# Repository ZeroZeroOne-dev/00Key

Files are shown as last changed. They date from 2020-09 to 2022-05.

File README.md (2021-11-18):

# 001Key

Custom 75% Keyboard.

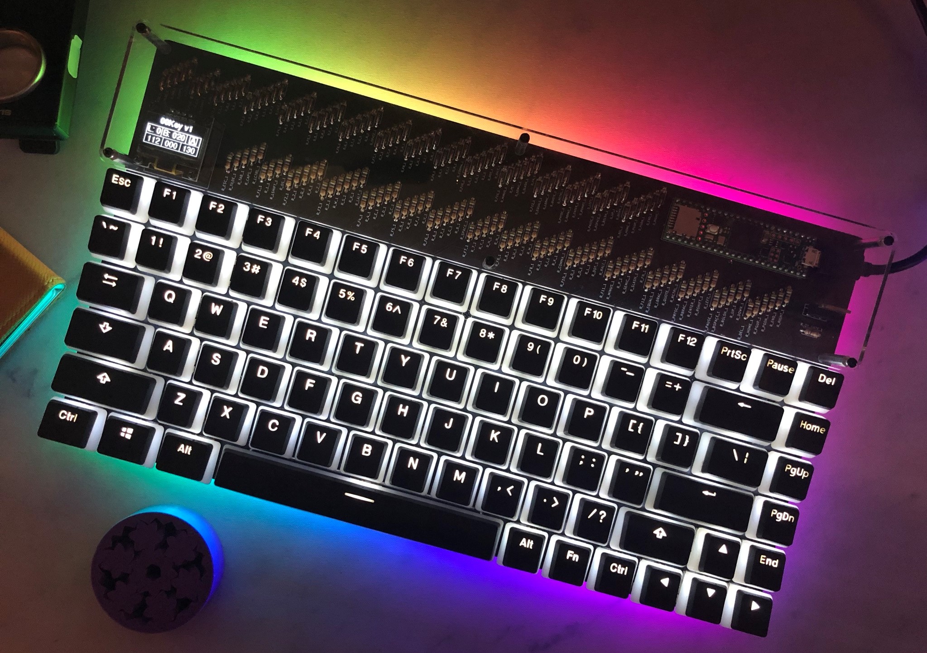
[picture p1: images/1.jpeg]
build


## Hardware

- Teensy 4.1 development board
- SSD1306 0.96 Inch OLED Display
- MX & Alps switch support
- Backlight (single color) support
- RGB Underglow support

## Firmware

Custom firmware, has layer, OLED, Backlight, Underglow support

## OLED display

Displays currently shows

- capslock status
- Selected layer
- backlight intensity 
- Underglow collor selection (RGB Values)

## Underglow

3 Effects
- Solid color
- Rotating rainbow
- Off

## PCB

- Designed in kicad
- Used freerouting for traces

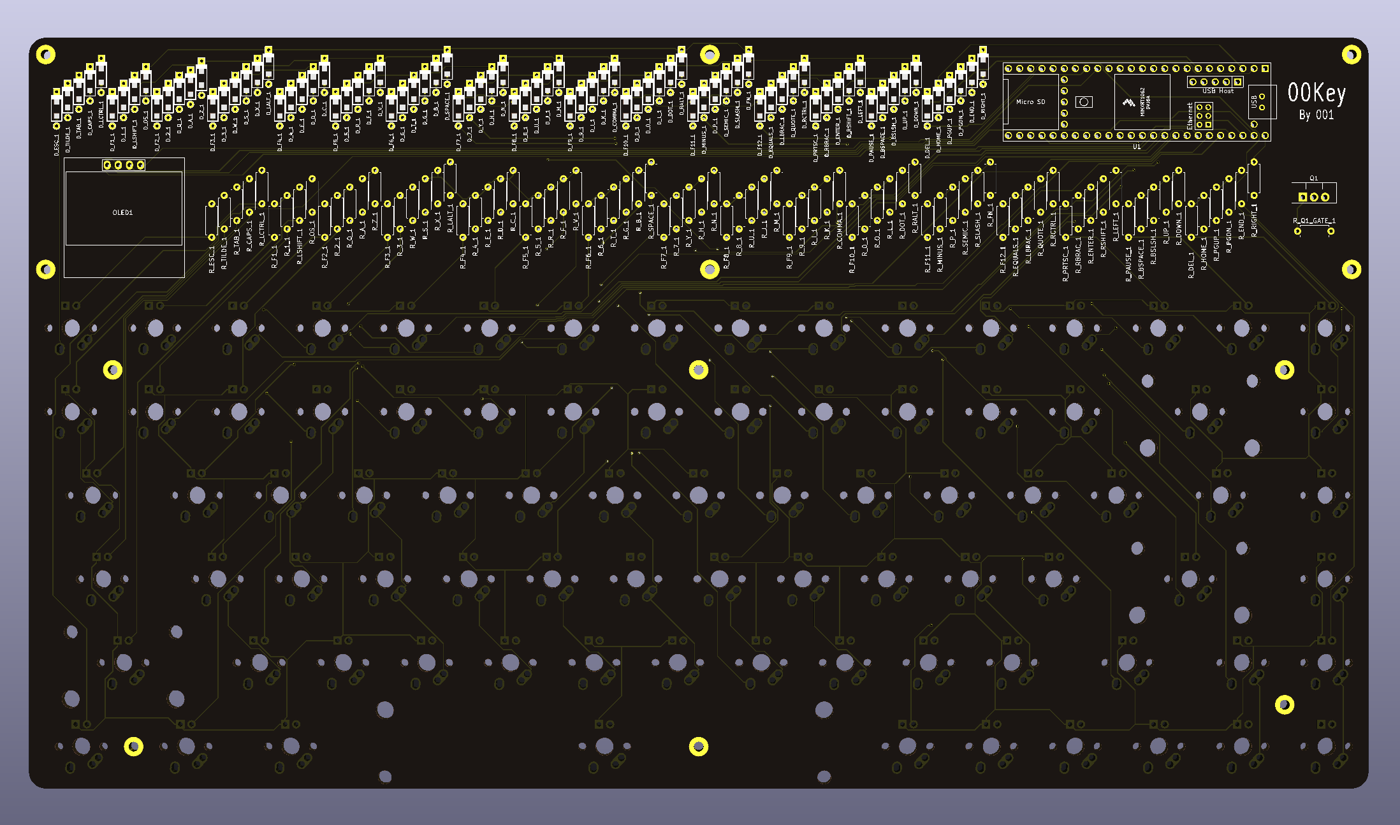
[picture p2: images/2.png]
pcbrender


## Backplate

- Designed in FreeCAD
- Spaced from PCB with (10mm) standoffs
- STL files included for 3D printing in 2 parts

## Case

Stacked acrylic case

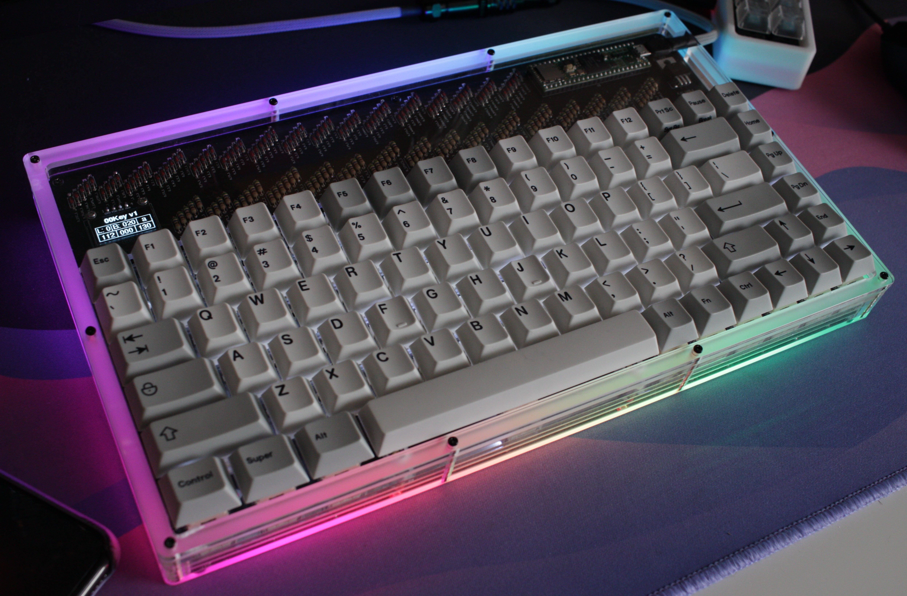
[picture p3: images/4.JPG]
case


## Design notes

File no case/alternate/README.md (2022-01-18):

# Overview

Another bottom to place the PCB on with a 7% slope. This one is almost certinaly only useful if it 
is printed out of clear PETG. Otherwise the light from the RGB LEDs can't be seen.

# OpenSCAD

This is designed with OpenSCAD which can be downloaded at https://www.openscad.org. If you want
to make changes the source files can be edited directly or use the customizer built into OpenSCAD, 
Window --> Customizer.

## Files

| Filename | Note |
| --- | ---- |
| 00keyBottom.scad | The main source file of the design, all the available variables are commented <br/>at the top of the file if you want to change something |
| spacer.scad | The source file for the spacers used to put between the PCB and case |
| cylinders.scad | A library used by spacers.scad, only the `hollowCylinder` module is used | 
| cubes.scad | A library used by 00keyBottom.scad, only the `roundedCube` module is used |

# Assembly
     
The 2 LED strips should be fastened to the bottom of the PCB using Kapton tape or your favorite 
adhesive. They should be positioned so they line up with the slots on the bottom of the case.

The default design intends that the PCB is connected to the case using M2x4x3.5 heat set inserts with
a 2.5 mm spacer in between case and PCB. The size of the hole for the heatset inserts can be
changed in `00keyBottom.scad` if a different size is wanted. The spacers can be made thicker in
`spacer.scad` if thicker spacers are wanted/needed.

The spacers can be held in place with a dab of super glue during assembly so they stay in place as 
the PCB is screwed down.

*NOTE:* I snipped the legs of the controller pins so they didn't stick so far down. If you 
don't do this you will probably need thicker spacers.
          
# Side View
     
Side View
             
# Bottom View

Note that this picture differs slightly from the final design. There is now an anti-flex support running down the middle
of the bottom of the case length-wise.

RGB LED

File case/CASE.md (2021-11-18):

## Acrylic case

The acrylic case can be assembled using M2 standoffs (thin,non-hex), use both male-to-female and female-to-female combined to get the correct lengths.

[amazon link](https://www.amazon.com/dp/B07768Q7YS/ref=cm_sw_em_r_mt_dp_5ADDDQNWRCW3QHP3A56S)

The svg file names should be pretty self-explanatory but here is another summary:

|File|Material|Thickness|Amount|
|---|---|---|---|
|1-foot_4mm_acrylic_x2.svg|Acrylic|4mm|0 - 2|
|2-bottom_5mm_acrylic_x1.svg|Acrylic|5mm|1|
|3-closed_4mm_acrylic_x3.svg|Acrylic|4mm|3|
|4-spacer_2mm_acrylic_x1.svg|Acrylic|2mm|1|
|5-plate_1.5mm_pom_x1.svg|POM|1.5mm|1|
|6-top_usb_3mm_acrylic_x2.svg|Acrylic|3mm|2|
|7-top_2mm_acrylic_x1.svg|Acrylic|2mm|1|

## Manufacturer

You might need to change the coloring and layers of the svg files to the specification of your manufacturer. 
You do have many color choices when using acrylic so let your imagination go wild!

If you're in europe I can recommend [snijlab.nl](https://snijlab.nl) and [laserbeest.nl](https://www.laserbeest.nl/).

For international I heard good things about [ponoko.com](https://www.ponoko.com/).

## Notes

You will have to bend your mosfet into an S-shape so it lays flat on the board.

## Anti-Flex

This part can be 3d printed and screwed to bottom of the top 6 holes of the pcb to provide some stability and to prevent the plate and pcb from flexing too much.

Depending on the calibration of your pinter you might need to tweak the length of the model (you can insert a pause at heigh and stop the print if its too long).

You can experiment yourself if you place them in all 6 holes or any other number of holes.

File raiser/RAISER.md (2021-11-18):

# OLED

The OLED used is a 128*64 SD1306; [aliexpress link](https://www.aliexpress.com/item/32638662748.html?spm=a2g0s.9042311.0.0.5d4e4c4d1zyBQ7)

(GND, VDD, SCK, SDA order)

## OLED Raiser

The oled raiser can be printed to give the lcd a bit of height and stability on the pcb.

Your oled screen might not be the same as the ones i used to its possible that you'll need to tweak the dimensions a bit.

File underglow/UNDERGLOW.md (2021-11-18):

## underglow

A 16 (2x8) led ws2812b rgb strip can be attached to the bottom of the pcb to provide underglow.

Should be soldered to the teensy underside like this: 

black = ground
red = 5v
green = data

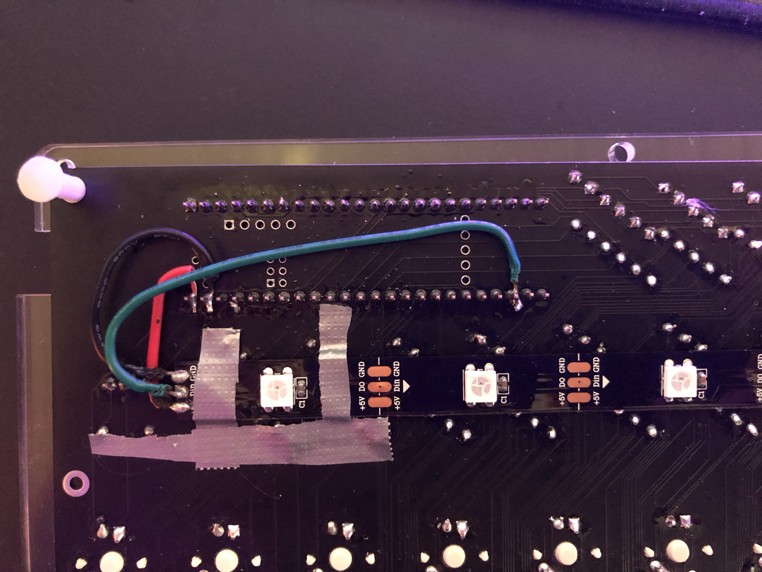
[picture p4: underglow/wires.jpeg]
wiring


In the default keymap the underglow effect can be toggled between static, rainbow, and off with Fn+U

The static effect can be changed using the Fn key in combination with the keys left (value down) and right (value up) of the R, G, and B keys. For example pressing Fn+E will make the Red value go down while pressing Fn+T will make the Red value go up.

## underglow spacer

This can be 3d printed to put over the standoffs between the pcb and the bottom plate 
(not when using the acrylic case).

Provides a convenient place to stick the rgb strips.

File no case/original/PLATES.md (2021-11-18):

## Plates

The top and bottom plate can be attached to the pcb using M2 standoffs (hex) both male-to-female and female-to-female. 

For the bottom you can choose yourself how long the standoffs you want to use are.
(Take into account if you want to put rgb strips in and if you do if you want to use the 3d-printable bracket, you can always switch them around later)

For the top you have to take into account the chosen height for the oled screen and in what position you put your mosfet (S-bended or upright).

[amazon link](https://www.amazon.com/dp/B071KDS14D/ref=cm_sw_em_r_mt_dp_7T1A5SNCJ3JM8QCT1W00)

The bottom plate can either be cut in 5mm acrylic (3mm might also work but i like the extra weight) or 3d printed.

The top plate should be cut in acrylic (2mm minimum for strength).

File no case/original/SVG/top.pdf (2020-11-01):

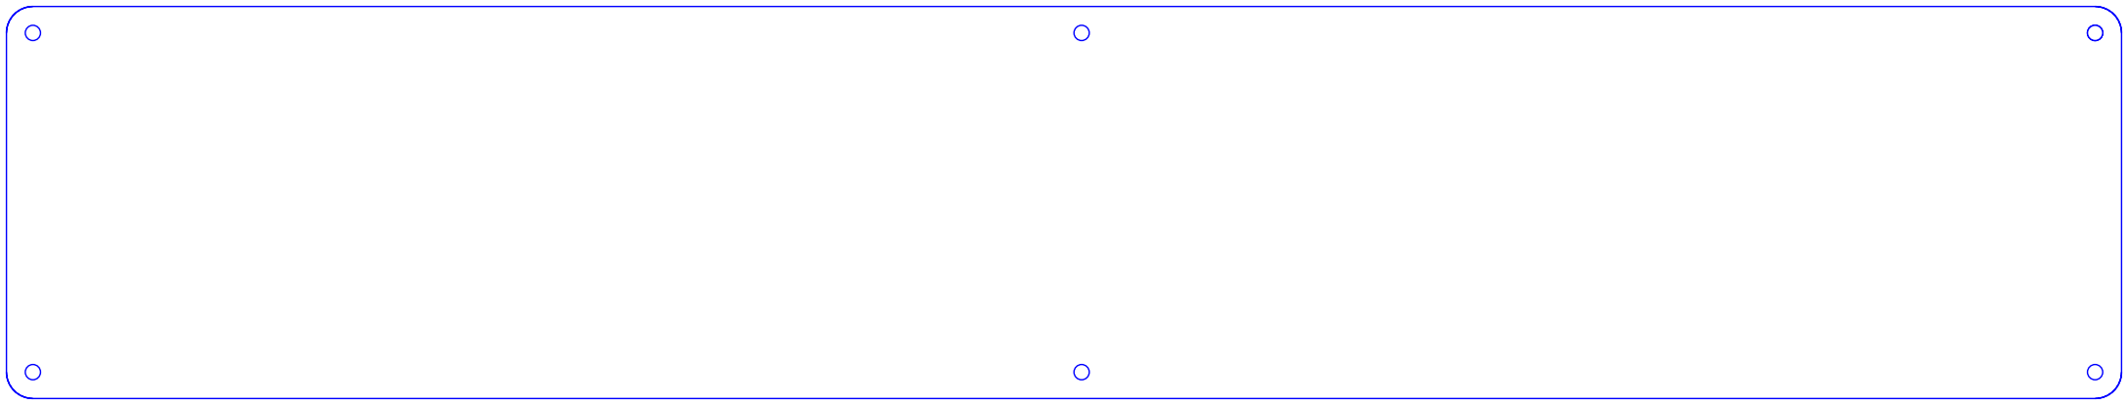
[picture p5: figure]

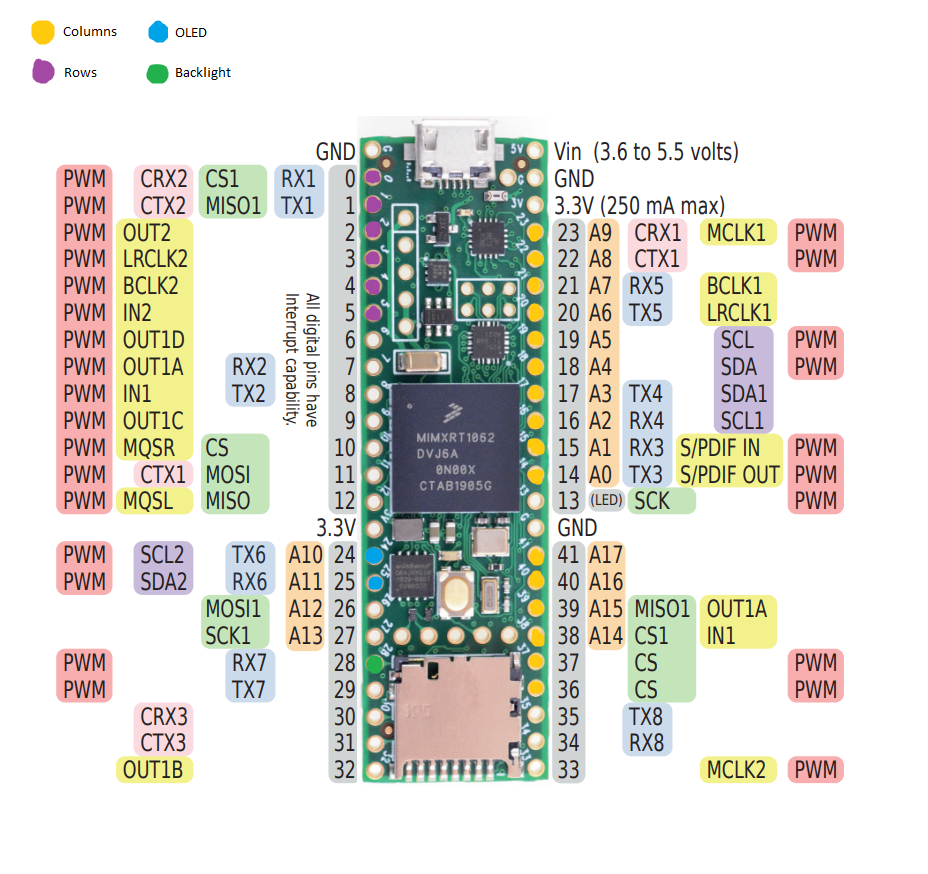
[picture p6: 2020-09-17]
reference/pins.png

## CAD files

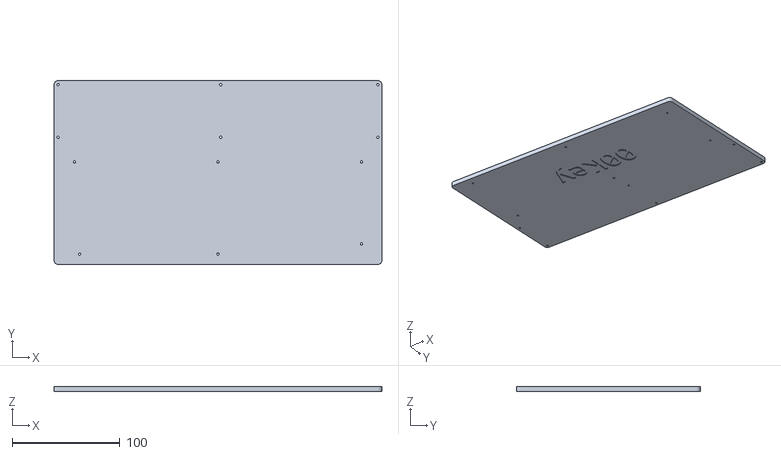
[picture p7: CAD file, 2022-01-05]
no case/original/STL/full.stl
304.8 x 170.8 x 5.00

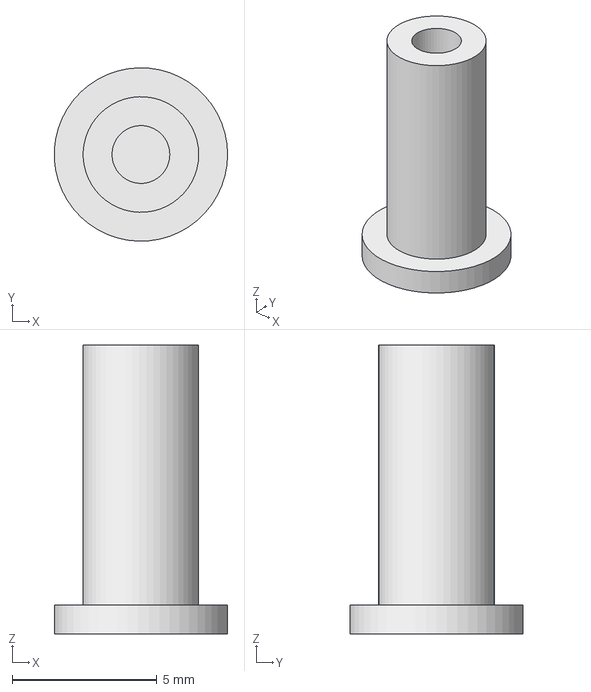
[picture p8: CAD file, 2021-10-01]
case/CAD/anti-flex.FCStd
5.99 x 6.00 x 10.0 mm

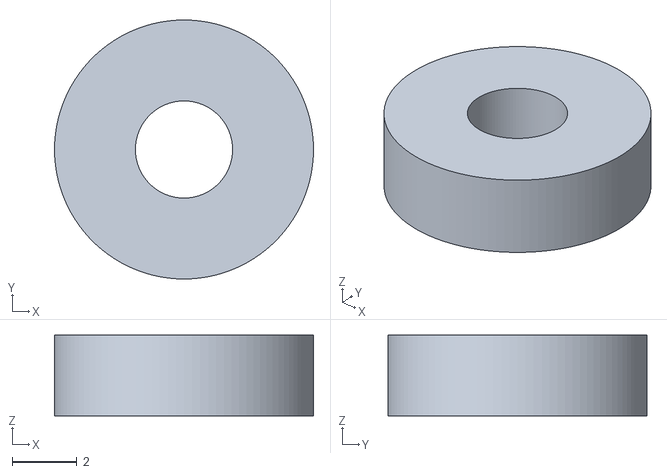
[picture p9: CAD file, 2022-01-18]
no case/alternate/STL/spacer.stl
8.00 x 8.00 x 2.50

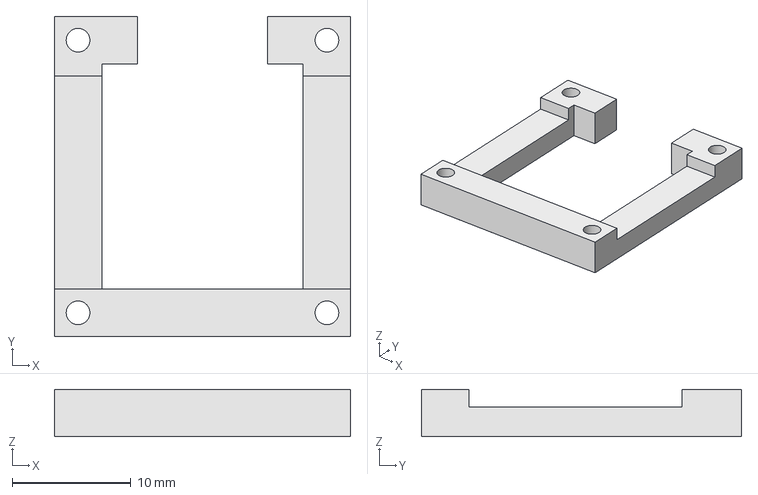
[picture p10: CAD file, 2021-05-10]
raiser/CAD/raiser.FCStd
25.0 x 27.0 x 4.00 mm

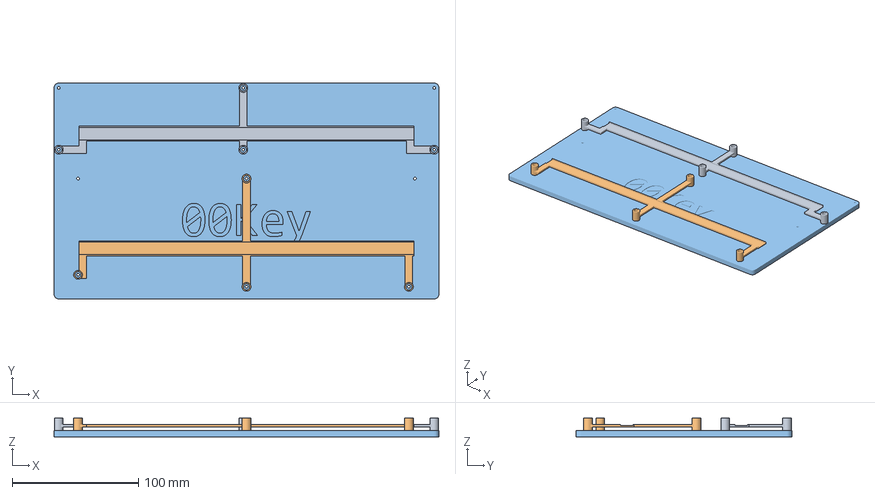
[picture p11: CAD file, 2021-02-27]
underglow/CAD/underglow spacer.FCStd
304.8 x 170.8 x 15.0 mm
top_all
bottom_all
plate

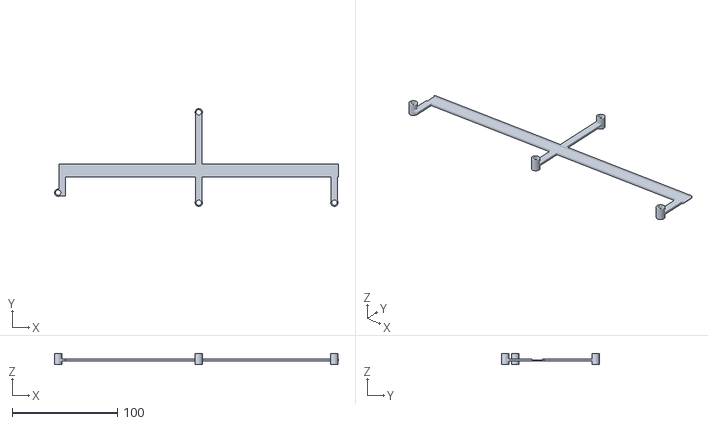
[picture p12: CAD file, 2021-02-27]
underglow/STL/underglow_spacer_bottom.stl
269.3 x 92.7 x 10.0

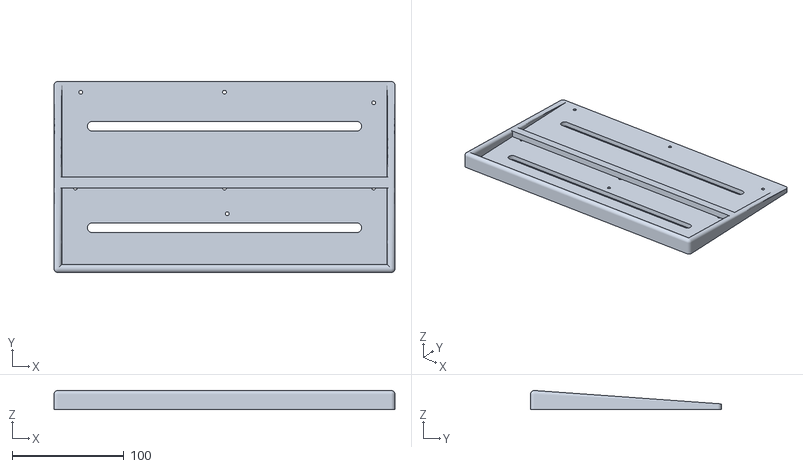
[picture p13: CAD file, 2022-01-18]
no case/alternate/STL/00keyBottom.stl
304.8 x 170.7 x 17.0

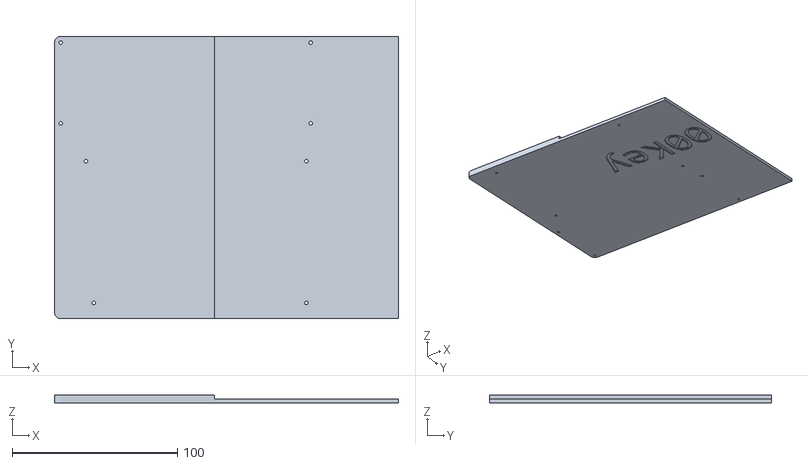
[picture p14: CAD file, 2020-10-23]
no case/original/STL/right.stl
208.1 x 170.8 x 5.00

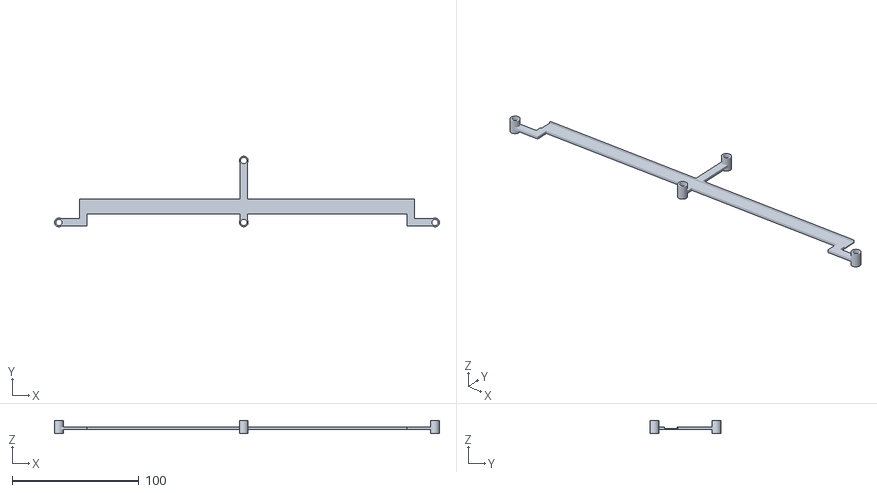
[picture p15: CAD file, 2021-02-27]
underglow/STL/underglow_spacer_top.stl
304.2 x 55.8 x 10.0

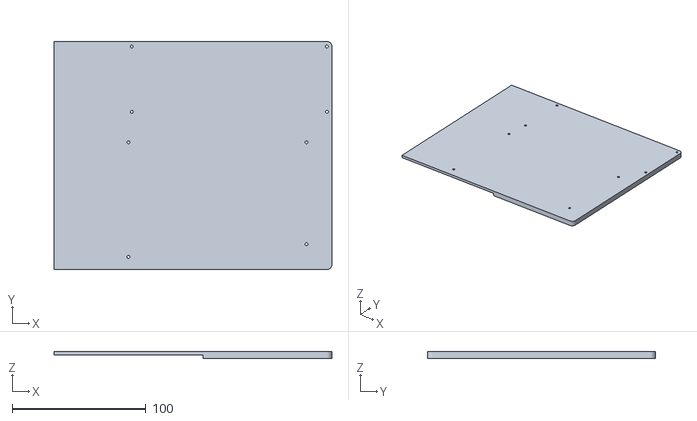
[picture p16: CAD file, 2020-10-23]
no case/original/STL/left.stl
208.1 x 170.8 x 5.00

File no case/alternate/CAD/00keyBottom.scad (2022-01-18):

use <cubes.scad>
 
$fn = 100;

//Length is x-axis and width is y-axis prior to to any rotation
length = 304.8;
width = 170.69;
height = 5;

//My radius gauge put the radius of the PCB corners somwhere betwen 3 and 4, went with 3.5 
//and it seems to match up pretty good
cornerRadius = 3.5;

//The outside diamter of the heatset insert you are using. I find it easier to insert these if the hole
//is tapered. So this value will be the diameter of the bottom of the hole. The diameter of the 
//top of the hole will be (heatsertOutsideDiameter + topHoleDelta). If you just want a non-tapered hole
//of a certain size just set the diameter appropriately and set topHoleDelta to 0
heatsertOutsideDiameter = 3.4;
topHoleDelta = 0.4;

//The height of the rear of the case, percent slope is (rearHeight / width * 100). 6-8% slope is common for keyboards. 
//10.5 gives ~6%, 
//12 gives ~7% slope.
//13.7 gives ~8%
//The calculated slope is printed in the console for convenience
rearHeight = 12;

//If you want to include the slots for the RGB lights this should be true, false otherwise
includeRgbLightHoles = true;

//The length (x-axis) of the RGB slot, make it long enough so all the LEDs are visible. The default 
//value should be good for 30 LED/meter strips. 
lightHoleLength = 245;

//The width (y-axis) of the RGB slot. This value is probably good to leave alone but you can adjust if you want
lightHoleWidth = 8.5;

//The y-axis position of the 1st RGB slot
lightHoleY1 = 40;

//The y-axis position of the 2nd RGB slot. Its default value will keep it equidistant from the edge as the 
//position of the 1st RGB slot
lightHoleY2 = width - lightHoleY1;

//How wide to make the anti-flex support. 
antiFlexWidth = 10;

//The position of the anti-flex support. The default value covers the holes a bit but the heatset inserts 
//don't come out the bottom so it doesn't matter. Can subtract antiFlexWidth from this if that bothers you 
antiFlexPosition = width / 2;

//Measured the hole distances on the PCB in KiCad with the measure tool. 
holeEdgeDistance = 3.81;
y1 = width - holeEdgeDistance;
y2 = 118.2;
y3 = 95.25;
y4 = 9.53;
holePositions = [
    //Row 1 (from top)
    [holeEdgeDistance, y1],
    [154.94, y1],
    [length - holeEdgeDistance, y1],
    //Row 2 (from top)
    [holeEdgeDistance, y2],
    [154.94, y2],
    [length - holeEdgeDistance, y2],
    //Row 3 (from top)
    [19.05, y3],
    [152.4, y3],
    [length - 19.05, y3],
    //Row 4 (from top)
    [23.88, y4],
    [152.4, y4],
    //The one-off hole in bottom right
    [length - 19.05, 19.05]
];

heatsertHoleTopDiameter = heatsertOutsideDiameter + topHoleDelta;

echo("Percent Slope: ", rearHeight / width * 100);
echo("LightHoleY1: ", lightHoleY1);
echo("LightHoleY2: ", lightHoleY2);

//Translating and rotating to get it in print orientation at the origin
//If you make changes comment out the translate/rotate line until you are ready to render/export
//as it gets confusing if you don't
translate([0, width, 0])  rotate([180, 0, 0]) 
main();

module main() {
    difference() {
        roundedCube(length = length, width = width, height = height, radius = cornerRadius, center = false, roundingShape = "circle", topRoundingShape = undef);
        screwHoles();
        if (includeRgbLightHoles) {
            rgbLightHoles();
        }
    }

    slant();
    //This will give additional support in the middle of the case, especially if RGB holes are included. If no RGB holes are included
    //you might be able to get away with not having this if you want.
    antiFlex();
}

module screwHoles() {
    for (pos = holePositions) {
       translate(concat(pos, -0.01)) cylinder(d1 = heatsertOutsideDiameter, d2 = heatsertHoleTopDiameter, h = height + 0.02, center = false);
    }
}

module slant() {
    slantPoints = [
        [cornerRadius, cornerRadius], //bottom left
        [cornerRadius, width - cornerRadius], //top left
        [length - cornerRadius, width - cornerRadius], //top right
        [length - cornerRadius, cornerRadius] //bottom right
    ];

    //Basically drawing a polyline with the rear/front objects hulled together
    hull() {
        translate(slantPoints[0]) frontObject();
        translate(slantPoints[1]) rearObject();
    }

    hull() {
        translate(slantPoints[1]) rearObject();
        translate(slantPoints[2]) rearObject();
    }

    hull() {
        translate(slantPoints[2]) rearObject();
        translate(slantPoints[3]) frontObject();
    }

    module rearObject() {
        //The radius of the sphere is effectively added to the height of the cylinder so to make the rear be the height we 
        //actually want need to subtract the radius
        cylinderHeight = rearHeight - cornerRadius;

        translate([0, 0, -cylinderHeight]) {
            cylinder(r = cornerRadius, h = cylinderHeight);
            sphere(r = cornerRadius);
        }
    }

    module frontObject() {
        //Don't want to add any meaningful dimension to the front of the case so make this
        //super thin just so we have something to hull with
        bottomHeight = 0.01;
        translate([0, 0, -bottomHeight]) cylinder(r = cornerRadius, h = bottomHeight);
    }
}

module rgbLightHoles() {
    x = length / 2 - lightHoleLength / 2;
    translate([x, lightHoleY1, -0.5]) rgbLightHole();
    translate([x, lightHoleY2, -0.5]) rgbLightHole();

    module rgbLightHole() {
        adjustedLength = lightHoleLength - lightHoleWidth;
        
        //Translate the radius of the hole so it is at the origin
        translate([lightHoleWidth / 2, 0, 0]) hull() {
            cylinder(d = lightHoleWidth, h = height + 1);
            translate([adjustedLength, 0, 0]) cylinder(d = lightHoleWidth, h = height + 1);
        }
    }
}

module antiFlex() {
    //We want the antiflex support to be the same height as the slanted walls at its position. So 
    //we will draw the slant again and intersect a cube with it, then hull the result of the intersection.
    //I normally like drawing my objects at the origin in modules and them moving them into position where they 
    //are used; however, in this case the height of the antiFlex object depends on where it is positioned on the y-axis 
    //so have to move it into position here as well
    height = rearHeight + 10;
    hull() {
        intersection() {
            slant();
            translate([0, antiFlexPosition, -height]) cube([length, antiFlexWidth, height]);
        }
    }
}

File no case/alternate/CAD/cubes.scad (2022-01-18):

//dimensionType -- "inner" if the passed in dimensions are for the inside of the box i.e. the hollow parts (default), 
//  "outer" if the passed in dimensions are for the outside of the box. In this case the dimensions of the hollow part
//  will be calculated taking into account the passed in wallThickness
//hasFloor = true to make it a box with a floor, false to make the hole all the way through
module hollowCube(length = 10, width = 10, height = 10, wallThickness = 3, hasFloor = true, dimensionType = "inner", center = false, debug = false) {
    doubleWallThickness = wallThickness * 2;

    if (dimensionType == "inner") {
        echo("InnerDimensioned Hollow Cube");
        innerDimensioned();
    } else {
        echo("OuterDimensioned Hollow Cube");
        outerDimensioned();
    }

    module innerDimensioned() {
        difference() {
            //Exterior
            exteriorLength = length + doubleWallThickness;
            exteriorWidth = width + doubleWallThickness;
            if (debug) {
                echo("Wall Thickess: ", wallThickness);
                echo("Double Wall Thickess: ", doubleWallThickness);
                echo("Inner Length: ", length);
                echo("Inner Width: ", width);
                echo("Exterior Length: ", exteriorLength);
                echo("Exterior Width: ", exteriorWidth);
            }

            cube([exteriorLength, exteriorWidth, height], center = center);

            //Hollow interior
            x = center == true ? 0 : wallThickness;
            y = center == true ? 0 : wallThickness;
            if (hasFloor == true) {
                translate([x, y, wallThickness]) cube([length, width, height], center = center);
            } else {
                translate([x, y, -1]) cube([length, width, height + 10], center = center);
            }
        }
    }

    module outerDimensioned() {
        difference() {
            //Exterior
            innerLength = length - doubleWallThickness;
            innerWidth = width - doubleWallThickness;
            echo("Wall Thickess: ", wallThickness);
            echo("Double Wall Thickess: ", doubleWallThickness);
            echo("Exterior Length: ", length);
            echo("Exterior Width: ", width);
            echo("Inner Length: ", innerLength);
            echo("Inner Width: ", innerWidth);

            cube([length, width, height], center = center);

            //Hollow interior
            x = center ? 0 : wallThickness;
            y = center ? 0 : wallThickness;
            if (hasFloor) {
                translate([x, y, wallThickness]) cube([innerLength, innerWidth, height], center = center);
            } else {
                translate([x, y, -1]) cube([innerLength, innerWidth, height + 10], center = center);
            }
        }
    }
}

//dimensionType -- "inner" if the passed in dimensions are for the inside of the box i.e. the hollow parts (default), 
//  "outer" if the passed in dimensions are for the outside of the box. In this case the dimensions of the hollow part
//  will be calculated taking into account the passed in wallThickness
//hasFloor = true to make it a box with a floor, false to make the hole all the way through
//roundingShape = one of "sphere" or "circle", a sphere rounds the object along all edges, circle rounds just the corners
//  if topRoundingShape is undef this applies to all edges
//topRoundingShape = one of "sphere" or "circle", a sphere rounds the object along all edges, circle rounds just the corners
//  if defined is the rounding shape of the top edges in case you want top edges rounded differently (can be handy for lids)
module hollowRoundedCube(length = 10, width = 10, height = 10, radius = 1, wallThickness = 3, floorThickness = 3, hasFloor = true, 
    roundingShape = "sphere", topRoundingShape = undef, dimensionType = "inner", roundedInterior = false, center = false) {

    topRoundingShape = topRoundingShape == undef ? roundingShape : topRoundingShape;
    echo("TopRoundingShape: ", topRoundingShape);

    doubleWallThickness = wallThickness * 2;
    if (dimensionType == "inner") {
        innerDimensioned();
    } else {
        outerDimensioned();
    }

    module innerDimensioned() {
        difference() {
            //Exterior
            roundedCube(length + doubleWallThickness, width + doubleWallThickness, height, radius, roundingShape = roundingShape, 
                topRoundingShape = topRoundingShape, center = center);

            //Hollow interior
            x = center ? 0 : wallThickness;
            y = center ? 0 : wallThickness;
            if (hasFloor) {
                translate([x, y, floorThickness]) hollowInterior(length, width, height, center = center);
            } else {
                translate([x, y, -1]) hollowInterior(length, width, height + 10, center = center);
            }
        }
    }

    module outerDimensioned() {
        innerLength = length - doubleWallThickness;
        innerWidth = width - doubleWallThickness;
        difference() {
            //Exterior
            roundedCube(length, width, height, radius, roundingShape = roundingShape, topRoundingShape = topRoundingShape, center = center);

            //Hollow interior
            x = center ? 0 : wallThickness;
            y = center ? 0 : wallThickness;
            if (hasFloor) {
                translate([x, y, floorThickness]) hollowInterior(innerLength, innerWidth, height, center = center);
            } else {
                translate([x, y, -1]) hollowInterior(innerLength, innerWidth, height + 10, center = center);
            }
        }
    }

    module hollowInterior(length, width, height, center = center) {
        if (roundedInterior) {
            roundedCube(length, width, height, radius, roundingShape = roundingShape, topRoundingShape = topRoundingShape, center = center);
        } else {
            cube([length, width, height], center = center);
        }
    }
}

/*
    Creates rounded cube without minkowsi, this one performs a lot better than minowski cube which may be important 
    in larger designs

    roundingSphere = one of "sphere" or "circle", a sphere rounds the object along all edges, circle rounds just the corners
*/
module roundedCube(length = 10, width = 10, height = 10, radius = 1, center = false, roundingShape = "sphere", topRoundingShape = undef) {
    topRoundingShape = topRoundingShape == undef ? roundingShape : topRoundingShape;
    echo("roundedCube(), TopRoundingShape: ", topRoundingShape);
    if (center) {
        centeredRoundedCube();
    } else {
        nonCenteredRoundedCube();
    }

    module centeredRoundedCube() {
        bottomZ = roundingShape == "sphere" ? -(height - (radius * 2)) / 2 : -height / 2;
        topZ = topRoundingShape == "sphere" ? (height - (radius * 2)) / 2 : height / 2;

        echo("Centered Rounded Cube");
        echo("height: ", height);
        echo("BottomZ: ", bottomZ);
        echo("TopZ: ", topZ);

        hull() {
            translate([0, 0, bottomZ]) rectangle(length, width, radius, roundingShape);
            translate([0,0, topZ]) rectangle(length, width, radius, topRoundingShape);
        }
    }

    module nonCenteredRoundedCube() {
        z1 = topRoundingShape == "sphere" ? height - radius : height ;
        z2 = roundingShape == "sphere" ? radius : 0;
        x = length / 2;
        y = width / 2;
        echo("Non-Centered Rounded Cube");
        echo("length: ", length);
        echo("width: ", width);
        echo("height: ", height);
        echo("radius: ", radius);
        echo("x: ", x);
        echo("y: ", y);
        echo("Z1: ", z1);
        echo("Z2: ", z2);

        hull() {
            //Top
            translate([x, y, z1]) rectangle(length, width, radius, topRoundingShape);
            //Bottom
            translate([x, y, z2]) rectangle(length, width, radius, roundingShape);
        }
    }

    module rectangle(length, width, radius, roundingShape) {
        x = length - radius;
        y = width - radius;
        hull() {
            translate([(-x/2)+(radius/2), (-y/2)+(radius/2), 0]) roundingShape(radius, roundingShape);
            translate([(x/2)-(radius/2), (-y/2)+(radius/2), 0]) roundingShape(radius, roundingShape);
            translate([(-x/2)+(radius/2), (y/2)-(radius/2), 0]) roundingShape(radius, roundingShape);
            translate([(x/2)-(radius/2), (y/2)-(radius/2), 0]) roundingShape(radius, roundingShape);
        }

        module roundingShape(radius, roundingShape) {
            if (roundingShape == "sphere") {
                sphere(r = radius);
            } else {
                //make the extrusion small to make it a 3d object but don't add any size to the requested dimensions
                linear_extrude(0.000000000001) circle(r = radius);
            }
        }
    }
}

//Produces a 2D rounded square
module roundedSquare(length = 10, width = 10, radius = 1.0) {
    x = length - radius;
    y = width - radius;
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

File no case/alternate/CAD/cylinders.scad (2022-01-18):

use <../bosl/constants.scad>
include <../bosl/threading.scad>
use <shapes.scad>

//Creates a rod with threads on one or both ends. These rods can be threaded into each other
//
// endType -- one of "both", "male", or "female". If "both" the rod with have a female thread on one end and a male thread
//  on the other. If "male" one end with have a male thread and the other end will be flat. If "female" one end will have a 
//  female thread and the other end will be flat.
module rodWithThreads(diameter = 10, height = 100, endType = "both", threadDiameter = undef, threadLength = 5, threadPitch = 1, threadHoleAdjustment = 0.5, $fn = undef) {
    //For female threads difference this out of an object, send in a positive threadHoleAdjustment to make
    //the female hole bigger than the male threads
    threadDiameter = threadDiameter == undef ? diameter / 2 : threadDiameter;
    echo("Thread Diameter: ", threadDiameter);
    $fn = $fn == undef ? diameter * 2 : $fn;
    echo("$fn: ", $fn);
    difference() {

        union() {
            cylinder(d = diameter, h = height, center = false);

            //Create male thread if requested
            if (endType == "both" || endType == "male") {
                echo("****male****");
                translate([0, 0, height - 0.01]) thread(threadDiameter, threadLength, threadPitch);
            } 
        }

        //Create female thread if requested
        if (endType == "both" || endType == "female") {
            echo("****female****");
            translate([0, 0, -1]) thread(threadDiameter, threadLength + 2, threadPitch, threadHoleAdjustment, internal = true);
        }
    }

    module thread(threadDiameter, threadLength, threadPitch,  threadHoleAdjustment = 0, internal = false) {
        echo("ThreadHoleAdjustement: ", threadHoleAdjustment);
        threaded_rod(d = threadDiameter, l = threadLength, pitch = threadPitch, internal = internal, slop = threadHoleAdjustment, orient=ORIENT_Z, align=V_UP);
    }
}

// floorThickness - how thick the floor is if hasFloor is true, if left undefined then floor thickness is (outerDiameter - innerDiamter) / 2
module hollowCylinder(outerDiameter = 5, innerDiameter = 4, topOuterDiameter = undef, topInnerDiameter = undef, height = 10, center = false, hasFloor = false, 
    rounded = undef, floorThickness = undef) {
    topOuterDiameter = topOuterDiameter == undef ? outerDiameter : topOuterDiameter;
    topInnerDiameter = topInnerDiameter == undef ? innerDiameter : topInnerDiameter;
    echo("OuterDiameter: ", outerDiameter);
    echo("TopOuterDiameter: ", topOuterDiameter);
    echo("InnerDiameter: ", innerDiameter);
    echo("TopInnerDiameter: ", topInnerDiameter);
    echo("Rounded: ", rounded);
    echo("HasFloor: ", hasFloor);

    floorThickness = floorThickness == undef ? (outerDiameter - innerDiameter) / 2 : floorThickness;
    echo("FloorThickness (if hasFloor = true): ", floorThickness);


    if (rounded == undef) {
        nonRoundedTop();
    } else if (rounded == "top") {
        roundedTop();
    } else {
        roundedBottom();
    }

    z = hasFloor ? floorThickness : -0.01; 
    echo("Z: ", z);

    module nonRoundedTop() {
        difference() {
            cylinder(d1 = outerDiameter, d2 = topOuterDiameter, height, center = center);
            translate([0, 0, z]) cylinder(d1 = innerDiameter, d2 = topInnerDiameter, height + 1, center = center);
        }
    }

    //Center = true doesn't yet work with rounded cylinders
    module roundedTop() {
        //Wall thickness is the diameter of the circle that makes up the torus, so substract that from the height so we get the right height
        difference() {
            hull() {
                translate([0, 0, height - floorThickness]) torus(radiusOfTorus = topOuterDiameter / 2, diameterOfCircle = floorThickness, dimensionType = "outer", center = center);
                cylinder(d = outerDiameter, h = 1, center = center);
            }

            translate([0, 0, z]) cylinder(d1 = innerDiameter, d2 = topInnerDiameter, h = height + 1, center = center);
        }
    }

    //Center = true doesn't yet work with rounded cylinders
    module roundedBottom() {
        //Wall thickness is the diameter of the circle that makes up the torus, so substract that from the height so we get the right height
        difference() {
            hull() {
                translate([0, 0, height - 1]) cylinder(d1 = outerDiameter, d2 = topOuterDiameter, h = 1, center = center);
                torus(radiusOfTorus = outerDiameter / 2, diameterOfCircle = floorThickness, dimensionType = "outer", center = center);
            }

            translate([0, 0, z]) cylinder(d1 = innerDiameter, d2 = topInnerDiameter, h = height + 1, center = center);
        }
    }
}

//A cylinder with rouned edges on top and bottom
module roundedCylinder(diameter = 10, roundedRadius = 2, height = 20, center = false) {
    radius = diameter / 2;
    hull() {
        torus(radiusOfTorus = radius, diameterOfCircle = roundedRadius, dimensionType = "outer", center = center);
        translate([0, 0, height - roundedRadius]) torus(radiusOfTorus = diameter / 2, diameterOfCircle = roundedRadius, dimensionType = "outer", center = center);
    }
}

//Test
//rodWithThreads(diameter = 23, height = 100, endType = "both", threadLength = 20, threadPitch = 2, threadHoleAdjustment = 0.8);
//roundedCylinder(diameter = 20, roundedRadius = 4, center = false);
$fn = 100;
hollowCylinder(outerDiameter = 84, innerDiameter = 81, topOuterDiameter = 125, topInnerDiameter = 122, height = 113, center = false, hasFloor = true, rounded = "top", floorThickness = 3);

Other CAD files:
no case/alternate/CAD/spacer.scad
case/STL/anti-flex.stl
raiser/STL/raiser.stl

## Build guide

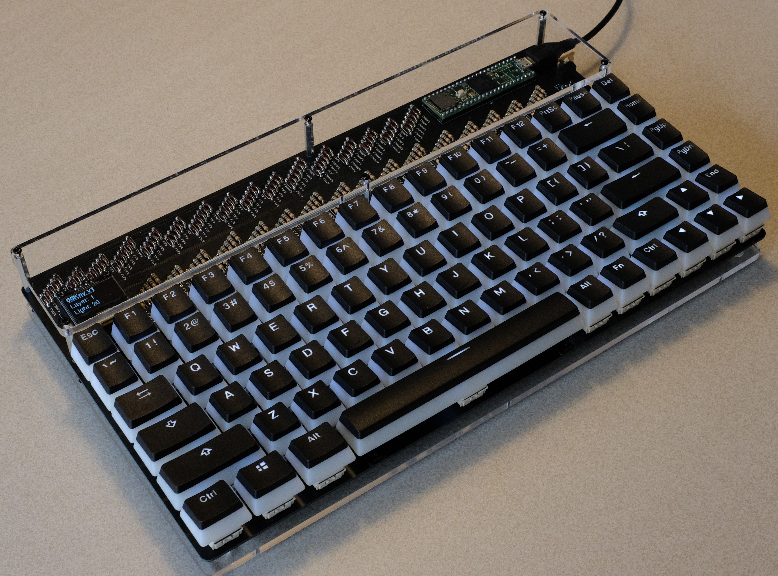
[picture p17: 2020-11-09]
images/build/DSCF2616.JPG

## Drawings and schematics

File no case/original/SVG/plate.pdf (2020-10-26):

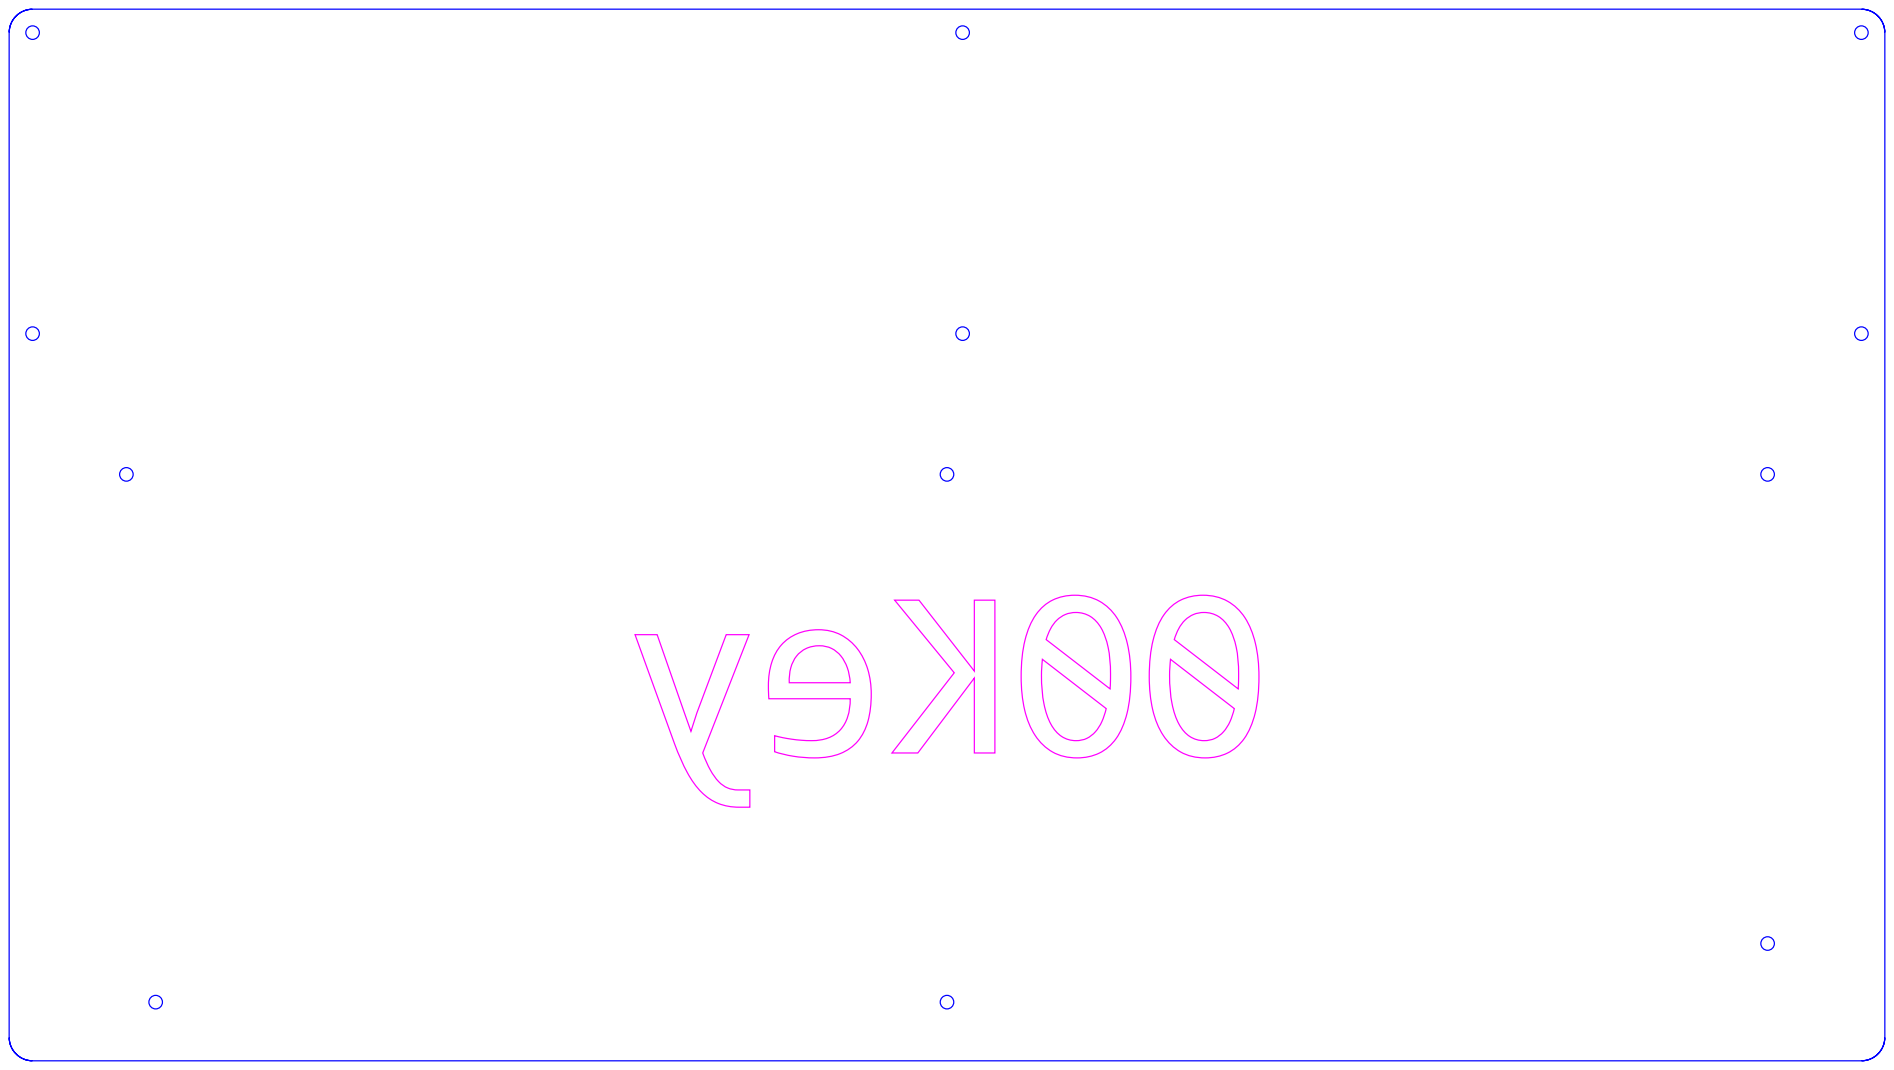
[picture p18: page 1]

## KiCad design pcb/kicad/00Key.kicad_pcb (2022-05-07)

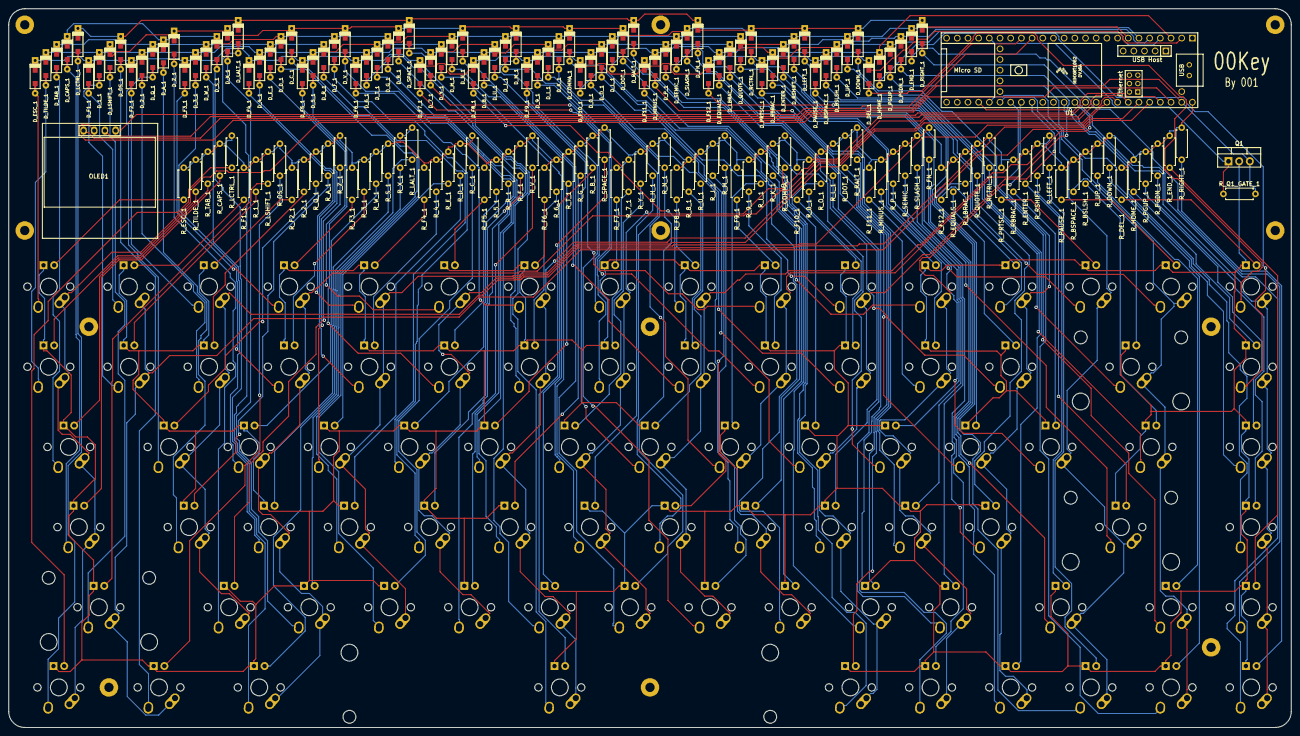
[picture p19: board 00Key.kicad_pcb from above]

Board: 2 copper layers, 304.8 x 170.8 mm, 268 parts (0 on the bottom side), 197 nets.

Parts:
D_0_1, D_1_1, D_2_1, D_3_1, D_4_1, D_5_1, D_6_1, D_7_1, D_8_1, D_9_1: D; D_SOD123_axial
D_A_1: D; D_SOD123_axial
D_BSLSH_1: D; D_SOD123_axial
D_BSPACE_1: D; D_SOD123_axial
D_B_1: D; D_SOD123_axial
D_CAPS_1: D; D_SOD123_axial
D_COMMA_1: D; D_SOD123_axial
D_C_1: D; D_SOD123_axial
D_DEL_1: D; D_SOD123_axial
D_DOT_1: D; D_SOD123_axial
D_DOWN_1: D; D_SOD123_axial
D_D_1: D; D_SOD123_axial
D_END_1: D; D_SOD123_axial
D_ENTER_1: D; D_SOD123_axial
D_EQUALS_1: D; D_SOD123_axial
D_ESC_1: D; D_SOD123_axial
D_E_1: D; D_SOD123_axial
D_F1_1, D_F2_1, D_F3_1, D_F4_1, D_F5_1, D_F6_1, D_F7_1, D_F8_1, D_F9_1, D_F10_1, D_F11_1, D_F12_1: D; D_SOD123_axial
D_FN_1: D; D_SOD123_axial
D_F_1: D; D_SOD123_axial
D_G_1: D; D_SOD123_axial
D_HOME_1: D; D_SOD123_axial
D_H_1: D; D_SOD123_axial
D_I_1: D; D_SOD123_axial
D_J_1: D; D_SOD123_axial
D_K_1: D; D_SOD123_axial
D_LALT_1: D; D_SOD123_axial
D_LBRAC_1: D; D_SOD123_axial
D_LCTRL_1: D; D_SOD123_axial
D_LEFT_1: D; D_SOD123_axial
D_LSHIFT_1: D; D_SOD123_axial
D_L_1: D; D_SOD123_axial
D_MINUS_1: D; D_SOD123_axial
D_M_1: D; D_SOD123_axial
D_N_1: D; D_SOD123_axial
D_OS_1: D; D_SOD123_axial
D_O_1: D; D_SOD123_axial
D_PAUSE_1: D; D_SOD123_axial
D_PGDN_1: D; D_SOD123_axial
D_PGUP_1: D; D_SOD123_axial
D_PRTSC_1: D; D_SOD123_axial
D_P_1: D; D_SOD123_axial
D_QUOTE_1: D; D_SOD123_axial
D_Q_1: D; D_SOD123_axial
D_RALT_1: D; D_SOD123_axial
D_RBRAC_1: D; D_SOD123_axial
D_RCTRL_1: D; D_SOD123_axial
D_RIGHT_1: D; D_SOD123_axial
D_RSHIFT_1: D; D_SOD123_axial
D_R_1: D; D_SOD123_axial
D_SEMIC_1: D; D_SOD123_axial
D_SLASH_1: D; D_SOD123_axial
D_SPACE_1: D; D_SOD123_axial
D_S_1: D; D_SOD123_axial
D_TAB_1: D; D_SOD123_axial
D_TILDE_1: D; D_SOD123_axial
D_T_1: D; D_SOD123_axial
D_UP_1: D; D_SOD123_axial
D_U_1: D; D_SOD123_axial
D_V_1: D; D_SOD123_axial
D_W_1: D; D_SOD123_axial
D_X_1: D; D_SOD123_axial
D_Y_1: D; D_SOD123_axial
D_Z_1: D; D_SOD123_axial
H_KEYS_BL: MountingHole_2.2mm_M2_Pad
H_KEYS_BM: MountingHole_2.2mm_M2_Pad
H_KEYS_BR: MountingHole_2.2mm_M2_Pad
H_KEYS_TL: MountingHole_2.2mm_M2_Pad
H_KEYS_TM: MountingHole_2.2mm_M2_Pad
H_KEYS_TR: MountingHole_2.2mm_M2_Pad
H_PLATE_BL: MountingHole_2.2mm_M2_Pad
H_PLATE_BR: MountingHole_2.2mm_M2_Pad
H_PLATE_MB: MountingHole_2.2mm_M2_Pad
H_PLATE_TL: MountingHole_2.2mm_M2_Pad
H_PLATE_TM: MountingHole_2.2mm_M2_Pad
H_PLATE_TR: MountingHole_2.2mm_M2_Pad
MX_0_1, MX_1_1, MX_2_1, MX_3_1, MX_4_1, MX_5_1, MX_6_1, MX_7_1, MX_8_1, MX_9_1: MX-LED; MX-1U
MX_A_1: MX-LED; MX-1U
MX_BSLSH_1: MX-LED; MX-1.5U
MX_BSPACE_1: MX-LED; MX-2U-ReversedStabilizers
MX_B_1: MX-LED; MX-1U
MX_CAPS_1: MX-LED; MX-1.75U
MX_COMMA_1: MX-LED; MX-1U
MX_C_1: MX-LED; MX-1U
MX_DEL_1: MX-LED; MX-1U
MX_DOT_1: MX-LED; MX-1U
MX_DOWN_1: MX-LED; MX-1U
MX_D_1: MX-LED; MX-1U
MX_END_1: MX-LED; MX-1U
MX_ENTER_1: MX-LED; MX-2.25U-ReversedStabilizers
MX_EQUALS_1: MX-LED; MX-1U
MX_ESC_1: MX-LED; MX-1U
MX_E_1: MX-LED; MX-1U
MX_F1_1, MX_F2_1, MX_F3_1, MX_F4_1, MX_F5_1, MX_F6_1, MX_F7_1, MX_F8_1, MX_F9_1, MX_F10_1, MX_F11_1, MX_F12_1: MX-LED; MX-1U
MX_FN_1: MX-LED; MX-1U
MX_F_1: MX-LED; MX-1U
MX_G_1: MX-LED; MX-1U
MX_HOME_1: MX-LED; MX-1U
MX_H_1: MX-LED; MX-1U
MX_I_1: MX-LED; MX-1U
MX_J_1: MX-LED; MX-1U
MX_K_1: MX-LED; MX-1U
MX_LALT_1: MX-LED; MX-1.25U
MX_LBRAC_1: MX-LED; MX-1U
MX_LCTRL_1: MX-LED; MX-1.25U
MX_LEFT_1: MX-LED; MX-1U
MX_LSHIFT_1: MX-LED; MX-2.25U-ReversedStabilizers
MX_L_1: MX-LED; MX-1U
MX_MINUS_1: MX-LED; MX-1U
MX_M_1: MX-LED; MX-1U
MX_N_1: MX-LED; MX-1U
MX_OS_1: MX-LED; MX-1.25U
MX_O_1: MX-LED; MX-1U
MX_PAUSE_1: MX-LED; MX-1U
MX_PGDN_1: MX-LED; MX-1U
MX_PGUP_1: MX-LED; MX-1U
MX_PRTSC_1: MX-LED; MX-1U
MX_P_1: MX-LED; MX-1U
MX_QUOTE_1: MX-LED; MX-1U
MX_Q_1: MX-LED; MX-1U
MX_RALT_1: MX-LED; MX-1U
MX_RBRAC_1: MX-LED; MX-1U
MX_RCTRL_1: MX-LED; MX-1U
MX_RIGHT_1: MX-LED; MX-1U
MX_RSHIFT_1: MX-LED; MX-1.75U
MX_R_1: MX-LED; MX-1U
MX_SEMIC_1: MX-LED; MX-1U
MX_SLASH_1: MX-LED; MX-1U
MX_SPACE_1: MX-LED; MX-6.25U
MX_S_1: MX-LED; MX-1U
MX_TAB_1: MX-LED; MX-1.5U
MX_TILDE_1: MX-LED; MX-1U
MX_T_1: MX-LED; MX-1U
MX_UP_1: MX-LED; MX-1U
MX_U_1: MX-LED; MX-1U
MX_V_1: MX-LED; MX-1U
MX_W_1: MX-LED; MX-1U
MX_X_1: MX-LED; MX-1U
MX_Y_1: MX-LED; MX-1U
MX_Z_1: MX-LED; MX-1U
OLED1: SSD1306; 128x64OLED
Q1: IRLZ44N; TO-220-3_Vertical
R_0_1, R_1_1, R_2_1, R_3_1, R_4_1, R_5_1, R_6_1, R_7_1, R_8_1, R_9_1: 470; R_Axial_DIN0207_L6.3mm_D2.5mm_P7.62mm_Horizontal
R_A_1: 470; R_Axial_DIN0207_L6.3mm_D2.5mm_P7.62mm_Horizontal
R_BSLSH_1: 470; R_Axial_DIN0207_L6.3mm_D2.5mm_P7.62mm_Horizontal
R_BSPACE_1: 470; R_Axial_DIN0207_L6.3mm_D2.5mm_P7.62mm_Horizontal
R_B_1: 470; R_Axial_DIN0207_L6.3mm_D2.5mm_P7.62mm_Horizontal
R_CAPS_1: 470; R_Axial_DIN0207_L6.3mm_D2.5mm_P7.62mm_Horizontal
R_COMMA_1: 470; R_Axial_DIN0207_L6.3mm_D2.5mm_P7.62mm_Horizontal
R_C_1: 470; R_Axial_DIN0207_L6.3mm_D2.5mm_P7.62mm_Horizontal
R_DEL_1: 470; R_Axial_DIN0207_L6.3mm_D2.5mm_P7.62mm_Horizontal
R_DOT_1: 470; R_Axial_DIN0207_L6.3mm_D2.5mm_P7.62mm_Horizontal
R_DOWN_1: 470; R_Axial_DIN0207_L6.3mm_D2.5mm_P7.62mm_Horizontal
R_D_1: 470; R_Axial_DIN0207_L6.3mm_D2.5mm_P7.62mm_Horizontal
R_END_1: 470; R_Axial_DIN0207_L6.3mm_D2.5mm_P7.62mm_Horizontal
R_ENTER_1: 470; R_Axial_DIN0207_L6.3mm_D2.5mm_P7.62mm_Horizontal
R_EQUALS_1: 470; R_Axial_DIN0207_L6.3mm_D2.5mm_P7.62mm_Horizontal
R_ESC_1: 470; R_Axial_DIN0207_L6.3mm_D2.5mm_P7.62mm_Horizontal
R_E_1: 470; R_Axial_DIN0207_L6.3mm_D2.5mm_P7.62mm_Horizontal
R_F1_1, R_F2_1, R_F3_1, R_F4_1, R_F5_1, R_F6_1, R_F7_1, R_F8_1, R_F9_1, R_F10_1, R_F11_1, R_F12_1: 470; R_Axial_DIN0207_L6.3mm_D2.5mm_P7.62mm_Horizontal
R_FN_1: 470; R_Axial_DIN0207_L6.3mm_D2.5mm_P7.62mm_Horizontal
R_F_1: 470; R_Axial_DIN0207_L6.3mm_D2.5mm_P7.62mm_Horizontal
R_G_1: 470; R_Axial_DIN0207_L6.3mm_D2.5mm_P7.62mm_Horizontal
R_HOME_1: 470; R_Axial_DIN0207_L6.3mm_D2.5mm_P7.62mm_Horizontal
R_H_1: 470; R_Axial_DIN0207_L6.3mm_D2.5mm_P7.62mm_Horizontal
R_I_1: 470; R_Axial_DIN0207_L6.3mm_D2.5mm_P7.62mm_Horizontal
R_J_1: 470; R_Axial_DIN0207_L6.3mm_D2.5mm_P7.62mm_Horizontal
R_K_1: 470; R_Axial_DIN0207_L6.3mm_D2.5mm_P7.62mm_Horizontal
R_LALT_1: 470; R_Axial_DIN0207_L6.3mm_D2.5mm_P7.62mm_Horizontal
R_LBRAC_1: 470; R_Axial_DIN0207_L6.3mm_D2.5mm_P7.62mm_Horizontal
R_LCTRL_1: 470; R_Axial_DIN0207_L6.3mm_D2.5mm_P7.62mm_Horizontal
R_LEFT_1: 470; R_Axial_DIN0207_L6.3mm_D2.5mm_P7.62mm_Horizontal
R_LSHIFT_1: 470; R_Axial_DIN0207_L6.3mm_D2.5mm_P7.62mm_Horizontal
R_L_1: 470; R_Axial_DIN0207_L6.3mm_D2.5mm_P7.62mm_Horizontal
R_MINUS_1: 470; R_Axial_DIN0207_L6.3mm_D2.5mm_P7.62mm_Horizontal
R_M_1: 470; R_Axial_DIN0207_L6.3mm_D2.5mm_P7.62mm_Horizontal
R_N_1: 470; R_Axial_DIN0207_L6.3mm_D2.5mm_P7.62mm_Horizontal
R_OS_1: 470; R_Axial_DIN0207_L6.3mm_D2.5mm_P7.62mm_Horizontal
R_O_1: 470; R_Axial_DIN0207_L6.3mm_D2.5mm_P7.62mm_Horizontal
R_PAUSE_1: 470; R_Axial_DIN0207_L6.3mm_D2.5mm_P7.62mm_Horizontal
R_PGDN_1: 470; R_Axial_DIN0207_L6.3mm_D2.5mm_P7.62mm_Horizontal
R_PGUP_1: 470; R_Axial_DIN0207_L6.3mm_D2.5mm_P7.62mm_Horizontal
R_PRTSC_1: 470; R_Axial_DIN0207_L6.3mm_D2.5mm_P7.62mm_Horizontal
R_P_1: 470; R_Axial_DIN0207_L6.3mm_D2.5mm_P7.62mm_Horizontal
R_Q1_GATE_1: 10K; R_Axial_DIN0207_L6.3mm_D2.5mm_P7.62mm_Horizontal
R_QUOTE_1: 470; R_Axial_DIN0207_L6.3mm_D2.5mm_P7.62mm_Horizontal
R_Q_1: 470; R_Axial_DIN0207_L6.3mm_D2.5mm_P7.62mm_Horizontal
R_RALT_1: 470; R_Axial_DIN0207_L6.3mm_D2.5mm_P7.62mm_Horizontal
R_RBRAC_1: 470; R_Axial_DIN0207_L6.3mm_D2.5mm_P7.62mm_Horizontal
R_RCTRL_1: 470; R_Axial_DIN0207_L6.3mm_D2.5mm_P7.62mm_Horizontal
R_RIGHT_1: 470; R_Axial_DIN0207_L6.3mm_D2.5mm_P7.62mm_Horizontal
R_RSHIFT_1: 470; R_Axial_DIN0207_L6.3mm_D2.5mm_P7.62mm_Horizontal
R_R_1: 470; R_Axial_DIN0207_L6.3mm_D2.5mm_P7.62mm_Horizontal
R_SEMIC_1: 470; R_Axial_DIN0207_L6.3mm_D2.5mm_P7.62mm_Horizontal
R_SLASH_1: 470; R_Axial_DIN0207_L6.3mm_D2.5mm_P7.62mm_Horizontal
R_SPACE_1: 470; R_Axial_DIN0207_L6.3mm_D2.5mm_P7.62mm_Horizontal
R_S_1: 470; R_Axial_DIN0207_L6.3mm_D2.5mm_P7.62mm_Horizontal
R_TAB_1: 470; R_Axial_DIN0207_L6.3mm_D2.5mm_P7.62mm_Horizontal
R_TILDE_1: 470; R_Axial_DIN0207_L6.3mm_D2.5mm_P7.62mm_Horizontal
R_T_1: 470; R_Axial_DIN0207_L6.3mm_D2.5mm_P7.62mm_Horizontal
R_UP_1: 470; R_Axial_DIN0207_L6.3mm_D2.5mm_P7.62mm_Horizontal
R_U_1: 470; R_Axial_DIN0207_L6.3mm_D2.5mm_P7.62mm_Horizontal
R_V_1: 470; R_Axial_DIN0207_L6.3mm_D2.5mm_P7.62mm_Horizontal
R_W_1: 470; R_Axial_DIN0207_L6.3mm_D2.5mm_P7.62mm_Horizontal
R_X_1: 470; R_Axial_DIN0207_L6.3mm_D2.5mm_P7.62mm_Horizontal
R_Y_1: 470; R_Axial_DIN0207_L6.3mm_D2.5mm_P7.62mm_Horizontal
R_Z_1: 470; R_Axial_DIN0207_L6.3mm_D2.5mm_P7.62mm_Horizontal
U1: Teensy4.1; Teensy41

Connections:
3.3V: OLED1.2, U1.46
5V: R_0_1.2, R_1_1.2, R_2_1.2, R_3_1.2, R_4_1.2, R_5_1.2, R_6_1.2, R_7_1.2, R_8_1.2, R_9_1.2, R_A_1.2, R_BSLSH_1.2, R_BSPACE_1.2, R_B_1.2, R_CAPS_1.2, R_COMMA_1.2, R_C_1.2, R_DEL_1.2, R_DOT_1.2, R_DOWN_1.2, R_D_1.2, R_END_1.2, R_ENTER_1.2, R_EQUALS_1.2, R_ESC_1.2, R_E_1.2, R_F1_1.2, R_F2_1.2, R_F3_1.2, R_F4_1.2, R_F5_1.2, R_F6_1.2, R_F7_1.2, R_F8_1.2, R_F9_1.2, R_F10_1.2, R_F11_1.2, R_F12_1.2, R_FN_1.2, R_F_1.2, R_G_1.2, R_HOME_1.2, R_H_1.2, R_I_1.2, R_J_1.2, R_K_1.2, R_LALT_1.2, R_LBRAC_1.2, R_LCTRL_1.2, R_LEFT_1.2, R_LSHIFT_1.2, R_L_1.2, R_MINUS_1.2, R_M_1.2, R_N_1.2, R_OS_1.2, R_O_1.2, R_PAUSE_1.2, R_PGDN_1.2, R_PGUP_1.2, R_PRTSC_1.2, R_P_1.2, R_QUOTE_1.2, R_Q_1.2, R_RALT_1.2, R_RBRAC_1.2, R_RCTRL_1.2, R_RIGHT_1.2, R_RSHIFT_1.2, R_R_1.2, R_SEMIC_1.2, R_SLASH_1.2, R_SPACE_1.2, R_S_1.2, R_TAB_1.2, R_TILDE_1.2, R_T_1.2, R_UP_1.2, R_U_1.2, R_V_1.2, R_W_1.2, R_X_1.2, R_Y_1.2, R_Z_1.2, U1.48
GND: OLED1.1, Q1.3, R_Q1_GATE_1.2, U1.47
LEDGND: MX_0_1.4, MX_1_1.4, MX_2_1.4, MX_3_1.4, MX_4_1.4, MX_5_1.4, MX_6_1.4, MX_7_1.4, MX_8_1.4, MX_9_1.4, MX_A_1.4, MX_BSLSH_1.4, MX_BSPACE_1.4, MX_B_1.4, MX_CAPS_1.4, MX_COMMA_1.4, MX_C_1.4, MX_DEL_1.4, MX_DOT_1.4, MX_DOWN_1.4, MX_D_1.4, MX_END_1.4, MX_ENTER_1.4, MX_EQUALS_1.4, MX_ESC_1.4, MX_E_1.4, MX_F1_1.4, MX_F2_1.4, MX_F3_1.4, MX_F4_1.4, MX_F5_1.4, MX_F6_1.4, MX_F7_1.4, MX_F8_1.4, MX_F9_1.4, MX_F10_1.4, MX_F11_1.4, MX_F12_1.4, MX_FN_1.4, MX_F_1.4, MX_G_1.4, MX_HOME_1.4, MX_H_1.4, MX_I_1.4, MX_J_1.4, MX_K_1.4, MX_LALT_1.4, MX_LBRAC_1.4, MX_LCTRL_1.4, MX_LEFT_1.4, MX_LSHIFT_1.4, MX_L_1.4, MX_MINUS_1.4, MX_M_1.4, MX_N_1.4, MX_OS_1.4, MX_O_1.4, MX_PAUSE_1.4, MX_PGDN_1.4, MX_PGUP_1.4, MX_PRTSC_1.4, MX_P_1.4, MX_QUOTE_1.4, MX_Q_1.4, MX_RALT_1.4, MX_RBRAC_1.4, MX_RCTRL_1.4, MX_RIGHT_1.4, MX_RSHIFT_1.4, MX_R_1.4, MX_SEMIC_1.4, MX_SLASH_1.4, MX_SPACE_1.4, MX_S_1.4, MX_TAB_1.4, MX_TILDE_1.4, MX_T_1.4, MX_UP_1.4, MX_U_1.4, MX_V_1.4, MX_W_1.4, MX_X_1.4, MX_Y_1.4, MX_Z_1.4, Q1.2
LEDPWM: Q1.1, R_Q1_GATE_1.1, U1.20
unnamed: D_0_1.2, MX_0_1.2
unnamed: D_1_1.2, MX_1_1.2
unnamed: D_2_1.2, MX_2_1.2
unnamed: D_3_1.2, MX_3_1.2
unnamed: D_4_1.2, MX_4_1.2
unnamed: D_5_1.2, MX_5_1.2
unnamed: D_6_1.2, MX_6_1.2
unnamed: D_7_1.2, MX_7_1.2
unnamed: D_8_1.2, MX_8_1.2
unnamed: D_9_1.2, MX_9_1.2
unnamed: D_A_1.2, MX_A_1.2
unnamed: D_BSLSH_1.2, MX_BSLSH_1.2
unnamed: D_BSPACE_1.2, MX_BSPACE_1.2
unnamed: D_B_1.2, MX_B_1.2
unnamed: D_CAPS_1.2, MX_CAPS_1.2
unnamed: D_COMMA_1.2, MX_COMMA_1.2
unnamed: D_C_1.2, MX_C_1.2
unnamed: D_DEL_1.2, MX_DEL_1.2
unnamed: D_DOT_1.2, MX_DOT_1.2
unnamed: D_DOWN_1.2, MX_DOWN_1.2
unnamed: D_D_1.2, MX_D_1.2
unnamed: D_END_1.2, MX_END_1.2
unnamed: D_ENTER_1.2, MX_ENTER_1.2
unnamed: D_EQUALS_1.2, MX_EQUALS_1.2
unnamed: D_ESC_1.2, MX_ESC_1.2
unnamed: D_E_1.2, MX_E_1.2
unnamed: D_F1_1.2, MX_F1_1.2
unnamed: D_F2_1.2, MX_F2_1.2
unnamed: D_F3_1.2, MX_F3_1.2
unnamed: D_F4_1.2, MX_F4_1.2
unnamed: D_F5_1.2, MX_F5_1.2
unnamed: D_F6_1.2, MX_F6_1.2
unnamed: D_F7_1.2, MX_F7_1.2
unnamed: D_F8_1.2, MX_F8_1.2
unnamed: D_F9_1.2, MX_F9_1.2
unnamed: D_F10_1.2, MX_F10_1.2
unnamed: D_F11_1.2, MX_F11_1.2
unnamed: D_F12_1.2, MX_F12_1.2
unnamed: D_FN_1.2, MX_FN_1.2
unnamed: D_F_1.2, MX_F_1.2
unnamed: D_G_1.2, MX_G_1.2
unnamed: D_HOME_1.2, MX_HOME_1.2
unnamed: D_H_1.2, MX_H_1.2
unnamed: D_I_1.2, MX_I_1.2
unnamed: D_J_1.2, MX_J_1.2
unnamed: D_K_1.2, MX_K_1.2
unnamed: D_LALT_1.2, MX_LALT_1.2
unnamed: D_LBRAC_1.2, MX_LBRAC_1.2
unnamed: D_LCTRL_1.2, MX_LCTRL_1.2
unnamed: D_LEFT_1.2, MX_LEFT_1.2
unnamed: D_LSHIFT_1.2, MX_LSHIFT_1.2
unnamed: D_L_1.2, MX_L_1.2
unnamed: D_MINUS_1.2, MX_MINUS_1.2
unnamed: D_M_1.2, MX_M_1.2
unnamed: D_N_1.2, MX_N_1.2
unnamed: D_OS_1.2, MX_OS_1.2
unnamed: D_O_1.2, MX_O_1.2
unnamed: D_PAUSE_1.2, MX_PAUSE_1.2
unnamed: D_PGDN_1.2, MX_PGDN_1.2
unnamed: D_PGUP_1.2, MX_PGUP_1.2
unnamed: D_PRTSC_1.2, MX_PRTSC_1.2
unnamed: D_P_1.2, MX_P_1.2
unnamed: D_QUOTE_1.2, MX_QUOTE_1.2
unnamed: D_Q_1.2, MX_Q_1.2
unnamed: D_RALT_1.2, MX_RALT_1.2
unnamed: D_RBRAC_1.2, MX_RBRAC_1.2
unnamed: D_RCTRL_1.2, MX_RCTRL_1.2
unnamed: D_RIGHT_1.2, MX_RIGHT_1.2
unnamed: D_RSHIFT_1.2, MX_RSHIFT_1.2
unnamed: D_R_1.2, MX_R_1.2
unnamed: D_SEMIC_1.2, MX_SEMIC_1.2
unnamed: D_SLASH_1.2, MX_SLASH_1.2
unnamed: D_SPACE_1.2, MX_SPACE_1.2
unnamed: D_S_1.2, MX_S_1.2
unnamed: D_TAB_1.2, MX_TAB_1.2
unnamed: D_TILDE_1.2, MX_TILDE_1.2
unnamed: D_T_1.2, MX_T_1.2
unnamed: D_UP_1.2, MX_UP_1.2
unnamed: D_U_1.2, MX_U_1.2
unnamed: D_V_1.2, MX_V_1.2
unnamed: D_W_1.2, MX_W_1.2
unnamed: D_X_1.2, MX_X_1.2
unnamed: D_Y_1.2, MX_Y_1.2
unnamed: D_Z_1.2, MX_Z_1.2
unnamed: MX_0_1.3, R_0_1.1
unnamed: MX_1_1.3, R_1_1.1
unnamed: MX_2_1.3, R_2_1.1
unnamed: MX_3_1.3, R_3_1.1
unnamed: MX_4_1.3, R_4_1.1
unnamed: MX_5_1.3, R_5_1.1
unnamed: MX_6_1.3, R_6_1.1
unnamed: MX_7_1.3, R_7_1.1
unnamed: MX_8_1.3, R_8_1.1
unnamed: MX_9_1.3, R_9_1.1
unnamed: MX_A_1.3, R_A_1.1
unnamed: MX_BSLSH_1.3, R_BSLSH_1.1
unnamed: MX_BSPACE_1.3, R_BSPACE_1.1
unnamed: MX_B_1.3, R_B_1.1
unnamed: MX_CAPS_1.3, R_CAPS_1.1
unnamed: MX_COMMA_1.3, R_COMMA_1.1
unnamed: MX_C_1.3, R_C_1.1
unnamed: MX_DEL_1.3, R_DEL_1.1
unnamed: MX_DOT_1.3, R_DOT_1.1
unnamed: MX_DOWN_1.3, R_DOWN_1.1
unnamed: MX_D_1.3, R_D_1.1
unnamed: MX_END_1.3, R_END_1.1
unnamed: MX_ENTER_1.3, R_ENTER_1.1
unnamed: MX_EQUALS_1.3, R_EQUALS_1.1
unnamed: MX_ESC_1.3, R_ESC_1.1
unnamed: MX_E_1.3, R_E_1.1
unnamed: MX_F1_1.3, R_F1_1.1
unnamed: MX_F2_1.3, R_F2_1.1
unnamed: MX_F3_1.3, R_F3_1.1
unnamed: MX_F4_1.3, R_F4_1.1
unnamed: MX_F5_1.3, R_F5_1.1
unnamed: MX_F6_1.3, R_F6_1.1
unnamed: MX_F7_1.3, R_F7_1.1
unnamed: MX_F8_1.3, R_F8_1.1
unnamed: MX_F9_1.3, R_F9_1.1
unnamed: MX_F10_1.3, R_F10_1.1
unnamed: MX_F11_1.3, R_F11_1.1
unnamed: MX_F12_1.3, R_F12_1.1
unnamed: MX_FN_1.3, R_FN_1.1
unnamed: MX_F_1.3, R_F_1.1
unnamed: MX_G_1.3, R_G_1.1
unnamed: MX_HOME_1.3, R_HOME_1.1
unnamed: MX_H_1.3, R_H_1.1
unnamed: MX_I_1.3, R_I_1.1
unnamed: MX_J_1.3, R_J_1.1
unnamed: MX_K_1.3, R_K_1.1
unnamed: MX_LALT_1.3, R_LALT_1.1
unnamed: MX_LBRAC_1.3, R_LBRAC_1.1
unnamed: MX_LCTRL_1.3, R_LCTRL_1.1
unnamed: MX_LEFT_1.3, R_LEFT_1.1
unnamed: MX_LSHIFT_1.3, R_LSHIFT_1.1
unnamed: MX_L_1.3, R_L_1.1
unnamed: MX_MINUS_1.3, R_MINUS_1.1
unnamed: MX_M_1.3, R_M_1.1
unnamed: MX_N_1.3, R_N_1.1
unnamed: MX_OS_1.3, R_OS_1.1
unnamed: MX_O_1.3, R_O_1.1
unnamed: MX_PAUSE_1.3, R_PAUSE_1.1
unnamed: MX_PGDN_1.3, R_PGDN_1.1
unnamed: MX_PGUP_1.3, R_PGUP_1.1
unnamed: MX_PRTSC_1.3, R_PRTSC_1.1
unnamed: MX_P_1.3, R_P_1.1
unnamed: MX_QUOTE_1.3, R_QUOTE_1.1
unnamed: MX_Q_1.3, R_Q_1.1
unnamed: MX_RALT_1.3, R_RALT_1.1
unnamed: MX_RBRAC_1.3, R_RBRAC_1.1
unnamed: MX_RCTRL_1.3, R_RCTRL_1.1
unnamed: MX_RIGHT_1.3, R_RIGHT_1.1
unnamed: MX_RSHIFT_1.3, R_RSHIFT_1.1
unnamed: MX_R_1.3, R_R_1.1
unnamed: MX_SEMIC_1.3, R_SEMIC_1.1
unnamed: MX_SLASH_1.3, R_SLASH_1.1
unnamed: MX_SPACE_1.3, R_SPACE_1.1
unnamed: MX_S_1.3, R_S_1.1
unnamed: MX_TAB_1.3, R_TAB_1.1
unnamed: MX_TILDE_1.3, R_TILDE_1.1
unnamed: MX_T_1.3, R_T_1.1
unnamed: MX_UP_1.3, R_UP_1.1
unnamed: MX_U_1.3, R_U_1.1
unnamed: MX_V_1.3, R_V_1.1
unnamed: MX_W_1.3, R_W_1.1
unnamed: MX_X_1.3, R_X_1.1
unnamed: MX_Y_1.3, R_Y_1.1
unnamed: MX_Z_1.3, R_Z_1.1
OLEDSCL: OLED1.3, U1.16
OLEDSDA: OLED1.4, U1.17
col0: MX_CAPS_1.1, MX_ESC_1.1, MX_LCTRL_1.1, MX_TAB_1.1, MX_TILDE_1.1, U1.45
col1: MX_1_1.1, MX_F1_1.1, MX_LSHIFT_1.1, MX_OS_1.1, U1.44
col2: MX_2_1.1, MX_A_1.1, MX_F2_1.1, MX_Q_1.1, MX_Z_1.1, U1.43
col3: MX_3_1.1, MX_F3_1.1, MX_LALT_1.1, MX_S_1.1, MX_W_1.1, MX_X_1.1, U1.42
col4: MX_4_1.1, MX_C_1.1, MX_D_1.1, MX_E_1.1, MX_F4_1.1, U1.41
col5: MX_5_1.1, MX_F5_1.1, MX_F_1.1, MX_R_1.1, MX_V_1.1, U1.40
col6: MX_6_1.1, MX_B_1.1, MX_F6_1.1, MX_G_1.1, MX_SPACE_1.1, MX_T_1.1, U1.39
col7: MX_7_1.1, MX_F7_1.1, MX_H_1.1, MX_N_1.1, MX_Y_1.1, U1.38
col8: MX_8_1.1, MX_F8_1.1, MX_J_1.1, MX_M_1.1, MX_U_1.1, U1.37
col9: MX_9_1.1, MX_COMMA_1.1, MX_F9_1.1, MX_I_1.1, MX_K_1.1, U1.36
col10: MX_0_1.1, MX_DOT_1.1, MX_F10_1.1, MX_L_1.1, MX_O_1.1, MX_RALT_1.1, U1.33
col11: MX_F11_1.1, MX_FN_1.1, MX_MINUS_1.1, MX_P_1.1, MX_SEMIC_1.1, MX_SLASH_1.1, U1.32
col12: MX_EQUALS_1.1, MX_F12_1.1, MX_LBRAC_1.1, MX_QUOTE_1.1, MX_RCTRL_1.1, U1.31
col13: MX_ENTER_1.1, MX_LEFT_1.1, MX_PRTSC_1.1, MX_RBRAC_1.1, MX_RSHIFT_1.1, U1.30
col14: MX_BSLSH_1.1, MX_BSPACE_1.1, MX_DOWN_1.1, MX_PAUSE_1.1, MX_UP_1.1, U1.29
col15: MX_DEL_1.1, MX_END_1.1, MX_HOME_1.1, MX_PGDN_1.1, MX_PGUP_1.1, MX_RIGHT_1.1, U1.28
row0: D_DEL_1.1, D_ESC_1.1, D_F1_1.1, D_F2_1.1, D_F3_1.1, D_F4_1.1, D_F5_1.1, D_F6_1.1, D_F7_1.1, D_F8_1.1, D_F9_1.1, D_F10_1.1, D_F11_1.1, D_F12_1.1, D_PAUSE_1.1, D_PRTSC_1.1, U1.2
row1: D_0_1.1, D_1_1.1, D_2_1.1, D_3_1.1, D_4_1.1, D_5_1.1, D_6_1.1, D_7_1.1, D_8_1.1, D_9_1.1, D_BSPACE_1.1, D_EQUALS_1.1, D_HOME_1.1, D_MINUS_1.1, D_TILDE_1.1, U1.3
row2: D_BSLSH_1.1, D_E_1.1, D_I_1.1, D_LBRAC_1.1, D_O_1.1, D_PGUP_1.1, D_P_1.1, D_Q_1.1, D_RBRAC_1.1, D_R_1.1, D_TAB_1.1, D_T_1.1, D_U_1.1, D_W_1.1, D_Y_1.1, U1.4
row3: D_A_1.1, D_CAPS_1.1, D_D_1.1, D_ENTER_1.1, D_F_1.1, D_G_1.1, D_H_1.1, D_J_1.1, D_K_1.1, D_L_1.1, D_PGDN_1.1, D_QUOTE_1.1, D_SEMIC_1.1, D_S_1.1, U1.5
row4: D_B_1.1, D_COMMA_1.1, D_C_1.1, D_DOT_1.1, D_END_1.1, D_LSHIFT_1.1, D_M_1.1, D_N_1.1, D_RSHIFT_1.1, D_SLASH_1.1, D_UP_1.1, D_V_1.1, D_X_1.1, D_Z_1.1, U1.6
row5: D_DOWN_1.1, D_FN_1.1, D_LALT_1.1, D_LCTRL_1.1, D_LEFT_1.1, D_OS_1.1, D_RALT_1.1, D_RCTRL_1.1, D_RIGHT_1.1, D_SPACE_1.1, U1.7

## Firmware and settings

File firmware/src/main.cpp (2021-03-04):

#include <Arduino.h>
#include "Globals.h"
#include "KeyMap.h"
#include "OLED.h"
#include "Backlight.h"
#include "Underglow.h"
#include "Scanner.h"
#include "Storage.h"
#include "Actions.h"

void setup()
{
  OLED::setup();
  Backlight::setup();
  Underglow::setup();
  Scanner::setup();
}

void loop()
{
  Scanner::loop();
  Actions::loop();
  OLED::loop();
  Underglow::loop();
  delay(SCAN_DELAY);
}

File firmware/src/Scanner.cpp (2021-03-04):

#include <Arduino.h>
#include "Scanner.h"
#include "Globals.h"
#include "KeyMap.h"
#include "Actions.h"

const byte rowPins[] = {0, 1, 2, 3, 4, 5};
const byte colPins[] = {23, 22, 21, 20, 19, 18, 17, 16, 15, 14, 41, 40, 39, 38, 37, 36};
bool statusMap[ROW_COUNT][COL_COUNT] = {{false}};

void Scanner::setup()
{
    for (byte i = 0; i < COL_COUNT; i++)
    {
        pinMode(colPins[i], INPUT_PULLUP);
    }

    for (byte i = 0; i < ROW_COUNT; i++)
    {
        pinMode(rowPins[i], OUTPUT);
    }
}

void pressKey(byte row, byte col)
{
    if (statusMap[row][col] == true)
    {
        return;
    }

    statusMap[row][col] = true;
    auto key = KeyMap::getKey(row, col);

    auto action = Actions::getAction(key);
    if (action == NULL || action(KeyDirection::DOWN))
    {
        Keyboard.press(key);
    }
}

void releaseKey(byte row, byte col)
{
    if (statusMap[row][col] == false)
    {
        return;
    }

    statusMap[row][col] = false;
    auto key = KeyMap::getKey(row, col);

    auto action = Actions::getAction(key);
    if (action == NULL || action(KeyDirection::UP))
    {
        Keyboard.release(key);
    }
}

void Scanner::loop()
{
    for (byte rowIndex = 0; rowIndex < ROW_COUNT; rowIndex++)
    {
        byte row = rowPins[rowIndex];

        digitalWrite(row, LOW);
        delayMicroseconds(PIN_CHANGE_DELAY);

        for (byte colIndex = 0; colIndex < COL_COUNT; colIndex++)
        {
            byte col = colPins[colIndex];

            if (digitalRead(col) == LOW)
            {
                pressKey(rowIndex, colIndex);
            }
            else
            {
                releaseKey(rowIndex, colIndex);
            }
        }

        digitalWrite(row, HIGH);
    }
}

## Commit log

2020-08-27 pre teensy
2020-08-27 teensy keyboard working
2020-08-27 OLED working with teensy
2020-08-29 layer switching
2020-08-29 layer switching working
2020-09-17 prototype entry
2020-09-21 initial PCB
    [00Key.kicad_pcb, 00Key.sch, switches.sch]
2020-09-21 added switches and diodes
    [switches.sch]
2020-09-21 connected rows and columns
    [switches.sch]
2020-09-23 why does kicad need numbered annotation? ugh
    [00Key.sch, switches.sch]
2020-09-23 added number to annotations
    [switches.sch]
2020-09-24 replaced with MX switches
    [switches.sch]
2020-09-25 correct key sizes
    [switches.sch]
2020-09-26 led resistor values
    [switches.sch]
2020-09-26 Resistor footprints
    [switches.sch]
2020-09-28 missing connection
    [switches.sch]
2020-09-28 keyboard layout in pcb
2020-09-30 diodes layout
    [00Key.kicad_pcb]
2020-10-01 start resistor placement
    [00Key.kicad_pcb]
2020-10-04 first layout
    [00Key.kicad_pcb, switches.sch]
2020-10-04 pulldown resistor mosfet
    [00Key.kicad_pcb, 00Key.sch]
2020-10-04 switches upside down
    [00Key.kicad_pcb]
2020-10-04 reversed stabs
    [00Key.kicad_pcb, switches.sch]
2020-10-04 reversed space stab
    [00Key.kicad_pcb, switches.sch]
2020-10-04 edge cuts, first mouthing holes
    [00Key.kicad_pcb]
2020-10-09 moving stuff around
    [00Key.kicad_pcb, switches.sch]
2020-10-10 hole labels
    [00Key.kicad_pcb]
2020-10-10 corner radius
    [00Key.kicad_pcb]
2020-10-13 moved pcb
    [00Key.kicad_pcb, 00Key.sch, switches.sch]
2020-10-18 basic plate design
2020-10-22 Basic plate
2020-10-23 plate stls
    [left.stl, right.stl]
2020-10-31 top plate
2020-11-09 screen raiser
    [raiser.FCStd, raiser.stl]
2020-11-19 Simple splashscreen on device start
2021-02-22 top underglow support, v1
    [raiser.FCStd, raiser.stl, spacer.stl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]
2021-02-23 extra supports
    [underglow spacer.FCStd]
2021-02-23 fixed missalignment
    [underglow spacer.FCStd, underglow_spacer_top.stl]
2021-02-24 bottom spacer start
    [underglow spacer.FCStd]
2021-03-01 change underglow color with buttons
2021-03-04 device name
2021-03-27 plate -> bottom
    [left.stl, right.stl]
2021-04-05 started working on the case
    [00Key_bottom.dxf, 00Key_closed.dxf, 00Key_open.dxf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]
2021-04-09 switched to normal CAD to see what im doing
    [00Key_bottom.dxf, 00Key_closed.dxf, 00Key_open.dxf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]
2021-04-12 case progress
2021-04-13 case complete
2021-04-14 final case commit
2021-08-12 started improving the case
2021-08-24 1.5mm petg plate v0.5
2021-08-28 added spacer for usb hole
2021-08-29 added holes in switch plate to reach pcb holes (rgb mount)
2021-10-01 changed the anti-flex hight a little
    [anti-flex.FCStd]
2022-01-05 added full plate 3d print
    [full.stl]
2022-01-17 Added new case and refactored directory structure to account for multiple case designs
    [00keyBottom.scad, 00keyBottom.stl, cubes.scad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]
2022-01-18 clarified some comments in the openscad code
    [00keyBottom.scad]
2022-05-07 lets just include the backup files
    [00Key.kicad_pcb, 00Key.kicad_sch, switches.kicad_sch]
2022-09-02 added a second static effect so i can switch between my fav solid colors
